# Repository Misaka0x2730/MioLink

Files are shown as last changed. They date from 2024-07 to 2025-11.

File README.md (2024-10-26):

# MioLink

This project is a port of the [Black Magic Probe project](https://github.com/blackmagic-debug/blackmagic) to Raspberry Pi RP2040 (2 Cortex-M0+ cores at 125MHz) MCU.  
The project is a USB debugger that operates via JTAG and SWD interfaces, supporting many ARM Cortex processors ([see supported device list here](https://black-magic.org/supported-targets.html)).  
It also supports debug output via Serial Wire Output (SWO) and RTT. Additionally, the device has an extra UART serial port that can be accessed through a second Virtual COM port.  
This README contains only the basic information: information about the hardware, how to build the firmware and flash the probe.  
Detailed instructions on how to use the debugger, how to configure SWO, RTT and etc. will be posted later in [the project's wiki](https://github.com/Misaka0x2730/MioLink/wiki).

# Hardware
## General information
The main board for this device is *MioLink* ([rev. A](https://github.com/Misaka0x2730/MioLink/blob/main/hardware/revA/MioLink_revA.pdf)/[rev. B](https://github.com/Misaka0x2730/MioLink/blob/main/hardware/revB/MioLink_revB.pdf)): RP2040 + 16Mbit (2MiB) QSPI Flash memory (W25Q16).  
At this moment, there are two revisions of *MioLink*: rev. A and rev. B.  
You can find information about their differences [here](https://github.com/Misaka0x2730/MioLink/wiki/MioLink-revisions-comparsion).  
[MioLink_Pico](https://github.com/Misaka0x2730/MioLink/blob/main/hardware/MioLink_Pico/revA/MioLink_Pico_revA.pdf) is a breakout board for Pico and Pico W featuring a power switch and voltage converters.  
Standard Pico and Pico W boards are also supported.  
The device type is determined at runtime, so all boards use the same firmware.  
[MioLink_adapter](https://github.com/Misaka0x2730/MioLink/blob/main/hardware/MioLink_adapter/revA/MioLink_adapter_revA.pdf) is an adapter that allows you to connect the probe with target boards that have different types of connectors.  
You can find all hardware CAD files (designed in KiCad) [here](https://github.com/Misaka0x2730/MioLink/tree/main/hardware).  

## Pinout
### MioLink and MioLink_Pico target connector pinout
*MioLink* and *MioLink_Pico* use the standard ARM 10-pin 0.1" connector and has additional 4-pin 0.1" UART connector:  


Pin | Name  | Description              | Pin | Name          | Description
:--:|:-----:|:------------------------:|:---:|:-------------:|:-----------------------------------------------------------------------:
1   | VTref | Target reference voltage | 2   | SWDIO/TMS     | SWD Data input/output / JTAG Test mode select
3   | GND   | Ground                   | 4   | SWDCLK/TCK    | SWD Clock / JTAG Test clock
5   | GND   | Ground                   | 6   | SWO/TDO/RX    | SWO Trace output / JTAG Test data output / UART Probe RX (Target TX)
7   | NC    | Not connected            | 8   | NC/TDI/TX     | Not connected for SWD / JTAG Test data input / UART Probe TX (Target RX)
9   | GND   | Ground                   | 10  | RESET         | Reset pin

#### UART connector pinout:

Pin | Name | Description                    | Pin | Name  | Description
:--:|:----:|:------------------------------:|:---:|:-----:|:------------------------:
1   | RX   | UART Probe RX (UART Target TX) | 2   | VTref | Target reference voltage
3   | TX   | UART Probe TX (UART Target RX) | 4   | GND   | Ground

### Pico/Pico W pinout


Pin       | Name       | Description
:--------:|:----------:|:------------------------------------------------------------------------:
10 (GP7)  | RESET      | Reset pin
11 (GP8)  | TX         | UART Probe TX (UART Target RX)
12 (GP9)  | RX         | UART Probe RX (UART Target TX)
13        | GND        | Ground
14 (GP10) | SWDCLK/TCK | SWD Clock / JTAG Test clock
15 (GP11) | SWDIO/TMS  | SWD Data input/output / JTAG Test mode select
16 (GP12) | NC/TDI/TX  | Not connected for SWD / JTAG Test data input / UART Probe TX (Target RX)
17 (GP13) | SWO/TDO/RX | SWO Trace output / JTAG Test data output / UART Probe RX (Target TX)
36        | 3V3        | 3.3V output from Pico

## Connecting target to probe
### Information about the Vtref pin (pin 1)
PLEASE, note that the Vtref pin (pin 1) on *MioLink* and *MioLink_Pico* MUST always be connected (internally or externally) to the logic level voltage of the target being debugged (from 1.65V to 5.5V) to power the level shifters inside the probe.  
If the target device operates at a 3.3V logic level, this pin can be powered internally by the probe, also in this case, the target can be powered by the probe if needed, and the maximum current is specified in the table below, but be careful, accidentally connecting anything to this pin that is not rated for 3.3V may lead to irreversible damage to the external device.  
3.3V power supply on this pin can be enabled with the GDB command ```monitor tpwr enable``` and disabled with the command ```monitor tpwr disable```. By default (after probe reset), it's disabled.  
Pico and Pico W are also able to provide 3.3V power for target, but it is recommended to keep the load on this pin less than 300mA, for more information see chapter 2.1, page 8 in [Pico datasheet](https://datasheets.raspberrypi.com/pico/pico-datasheet.pdf) and chapter 2.1, page 9 in [Pico W datasheet](https://datasheets.raspberrypi.com/picow/pico-w-datasheet.pdf).  
In all other cases, the Vtref pin (pin 1) functions as an input and must be connected to the logic level voltage of the target device.  
The allowable voltage range is from 1.65V to 5.5V.  

#### Maximum output current of the Vtref pin (pin 1):

Board | Max current
:----:|:----------:
MioLink | rev.A: ~200 mA;  rev.B: ~350 mA (min. 300, max. 400)
MioLink_Pico | ~200 mA (min. 175, max. 234)
Pico or Pico W | ~300 mA from 3V3 pin,  see recommendations in  Pico and Pico W datasheets.

### JTAG pins description

Pin | Description
:----:|:----------:
Vtref | Target reference voltage
GND   | Ground
TMS   | Test mode select
TCK   | Test clock
TDO   | Test data output
TDI   | Test data input
RESET | Optional reset pin

### SWD pins description

Pin    | Description
:-----:|:----------:
Vtref  | Target reference voltage
GND    | Ground
SWDIO  | Data input/output
SWDCLK | Clock signal
RESET  | Optional reset pin

# Building and flashing the probe
## Requirements
The following tools are required to build this project:
- git
- make
- Python
- cmake
- gcc
- arm-none-eabi-gcc

## Install all requirements on Windows
The simplest way to build the firmware under Windows environment is to use MinGW64.

Build steps:
1. Download and install [MSYS2](https://www.msys2.org/);
2. Run mingw64;
3. Upgrade packets, MinGW64 will be restarted:  ```pacman -Syu```
4. Install all requirements:  ```pacman -S git mingw-w64-x86_64-python mingw-w64-x86_64-make mingw-w64-x86_64-cmake mingw-w64-x86_64-arm-none-eabi-gcc mingw-w64-x86_64-gcc```
5. Clone this project with submodules:  ```git clone --recurse-submodules https://github.com/Misaka0x2730/MioLink.git```
6. Change current dir:  ```cd MioLink/firmware```

## Install all requirements on Ubuntu
1. Download and install all requirements:
```
cd /opt
sudo wget "https://developer.arm.com/-/media/Files/downloads/gnu/13.3.rel1/binrel/arm-gnu-toolchain-13.3.rel1-x86_64-arm-none-eabi.tar.xz"
sudo tar -xf arm-gnu-toolchain-13.3.rel1-x86_64-arm-none-eabi.tar.xz
sudo rm arm-gnu-toolchain-13.3.rel1-x86_64-arm-none-eabi.tar.xz
echo 'export PATH="$PATH":/opt/arm-gnu-toolchain-13.3.rel1-x86_64-arm-none-eabi/bin' >> ~/.bashrc
sudo apt-get install git python3 cmake
```
2. Clone this project with submodules into home directory:
```
cd ~
git clone --recurse-submodules https://github.com/Misaka0x2730/MioLink.git
```
3. Change current dir:  ```cd MioLink/firmware```

## Build debug image:
1. Create working directory:  ```mkdir debug```
2. Go to working directory:  ```cd debug```
3. Run cmake:  ```cmake -DCMAKE_BUILD_TYPE=Debug -G "MinGW Makefiles" ..```
4. Build image:  ```cmake --build .```
5. Use ```MioLink.uf2``` to flash device via factory USB-MSC bootloader.

## Build release image:
1. Create working directory:  ```mkdir release```
2. Go to working directory:  ```cd release```
3. Run cmake:  ```cmake -DCMAKE_BUILD_TYPE=Release -G "MinGW Makefiles" ..```
4. Build image:  ```cmake --build .```
5. Use ```MioLink.uf2``` to flash device via factory USB-MSC bootloader.

## How to flash the probe
1. Disconnect USB cable;
2. Press BOOT (BOOTSEL on Pico and Pico W) button;
3. Connect USB cable to PC;
4. Release BOOT (BOOTSEL on Pico and Pico W) button;
5. Drag-and-Drop ```MioLink.uf2``` file to mass storage device;
6. The device will be flashed and rebooted automatically, after which it is ready for use.

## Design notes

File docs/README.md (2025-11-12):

# MioLink

This project is a port of the [Black Magic Probe project](https://github.com/blackmagic-debug/blackmagic) to Raspberry Pi RP2040 (2 Cortex-M0+ cores at 125MHz) MCU.  
The project is a USB debugger that supports a lot of ARM Cortex target processors ([see supported device list here](https://black-magic.org/supported-targets.html)) via SWD and JTAG interfaces.  
It also supports debug output via Serial Wire Output (SWO) and RTT. Additionally, the device has an extra UART serial port that can be accessed through a second Virtual COM port.  
This README contains only the basic information: information about the hardware, how to build the firmware and flash the probe.  
Detailed instructions on how to use the debugger, how to configure SWO, RTT and etc. you can find on [the project's wiki](https://github.com/Misaka0x2730/MioLink/wiki).

# Table of Content
- [Hardware](#hardware)
  - [General information](#general-information)
  - [Pinout](#pinout)
    - [MioLink and MioLink_Pico pinout](#miolink-and-miolink_pico-pinout)
      - [Target connector pinout](#target-connector-pinout)
      - [UART connector pinout](#uart-connector-pinout)
    - [Pico/Pico W pinout](#picopico-w-pinout)
  - [Connecting target to probe](#connecting-target-to-probe)
    - [Information about the Vtref pin (pin 1)](#information-about-the-vtref-pin-pin-1)
      - [Maximum output current of the Vtref pin (pin 1)](#maximum-output-current-of-the-vtref-pin-pin-1)
    - [JTAG pins description](#jtag-pins-description)
    - [SWD pins description](#swd-pins-description)
- [Building and flashing the probe](#building-and-flashing-the-probe)
  - [Requirements](#requirements)
  - [Build on Windows](#build-on-windows)
    - [Install all requirements and clone the repository](#install-all-requirements-and-clone-the-repository)
    - [Build debug image](#build-debug-image)
    - [Build release image](#build-release-image)
  - [Build on Ubuntu](#build-on-ubuntu)
    - [Install all requirements and clone the repository](#install-all-requirements-and-clone-the-repository-1)
    - [Build debug image](#build-debug-image-1)
    - [Build release image](#build-release-image-1)
  - [Build on Mac OS](#build-on-mac-os)
    - [Install all requirements and clone the repository](#install-all-requirements-and-clone-the-repository-2)
    - [Build debug image](#build-debug-image-2)
    - [Build release image](#build-release-image-2)
  - [How to flash the probe](#how-to-flash-the-probe)
- [Known issues](#known-issues)

# Hardware
## General information
The main board for this device is *MioLink* ([rev. A](https://github.com/Misaka0x2730/MioLink/blob/main/hardware/revA/MioLink_revA.pdf)/[rev. B](https://github.com/Misaka0x2730/MioLink/blob/main/hardware/revB/MioLink_revB.pdf)): RP2040 + 16Mbit (2MiB) QSPI Flash memory (W25Q16).  
At this moment, there are two revisions of *MioLink*: rev. A and rev. B.  
You can find information about their differences [here](https://github.com/Misaka0x2730/MioLink/wiki/MioLink-revisions-comparsion).  
[MioLink_Pico](https://github.com/Misaka0x2730/MioLink/blob/main/hardware/MioLink_Pico/revA/MioLink_Pico_revA.pdf) is a breakout board for Pico and Pico W featuring a power switch and voltage converters.  
Standard Pico and Pico W boards are also supported.  
The device type is determined at runtime, so all boards use the same firmware.  
[MioLink_adapter](https://github.com/Misaka0x2730/MioLink/blob/main/hardware/MioLink_adapter/revA/MioLink_adapter_revA.pdf) is an adapter that allows you to connect the probe with target boards that have different types of connectors.  
You can find all hardware CAD files (designed in KiCad) [here](https://github.com/Misaka0x2730/MioLink/tree/main/hardware).  

## Pinout
### MioLink and MioLink_Pico pinout
#### Target connector pinout
*MioLink* and *MioLink_Pico* use the standard ARM 10-pin 0.1" connector and has additional 4-pin 0.1" UART connector:  


Pin | Name  | Description              | Pin | Name          | Description
:--:|:-----:|:------------------------:|:---:|:-------------:|:-----------------------------------------------------------------------:
1   | VTref | Target reference voltage | 2   | SWDIO/TMS     | SWD Data input/output / JTAG Test mode select
3   | GND   | Ground                   | 4   | SWDCLK/TCK    | SWD Clock / JTAG Test clock
5   | GND   | Ground                   | 6   | SWO/TDO/RX    | SWO Trace output / JTAG Test data output / UART Probe RX (Target TX)
7   | NC    | Not connected            | 8   | NC/TDI/TX     | Not connected for SWD / JTAG Test data input / UART Probe TX (Target RX)
9   | GND   | Ground                   | 10  | RESET         | Reset pin

#### UART connector pinout:

Pin | Name | Description                    | Pin | Name  | Description
:--:|:----:|:------------------------------:|:---:|:-----:|:------------------------:
1   | RX   | UART Probe RX (UART Target TX) | 2   | VTref | Target reference voltage
3   | TX   | UART Probe TX (UART Target RX) | 4   | GND   | Ground

### Pico/Pico W pinout


Pin       | Name       | Description
:--------:|:----------:|:------------------------------------------------------------------------:
10 (GP7)  | RESET      | Reset pin
11 (GP8)  | TX         | UART Probe TX (UART Target RX)
12 (GP9)  | RX         | UART Probe RX (UART Target TX)
13        | GND        | Ground
14 (GP10) | SWDCLK/TCK | SWD Clock / JTAG Test clock
15 (GP11) | SWDIO/TMS  | SWD Data input/output / JTAG Test mode select
16 (GP12) | NC/TDI/TX  | Not connected for SWD / JTAG Test data input / UART Probe TX (Target RX)
17 (GP13) | SWO/TDO/RX | SWO Trace output / JTAG Test data output / UART Probe RX (Target TX)
36        | 3V3        | 3.3V output from Pico

## Connecting target to probe
### Information about the Vtref pin (pin 1)
PLEASE, note that the Vtref pin (pin 1) on *MioLink* and *MioLink_Pico* MUST always be connected (internally or externally) to the logic level voltage of the target being debugged (from 1.65V to 5.5V) to power the level shifters inside the probe.  
If the target device operates at a 3.3V logic level, this pin can be powered internally by the probe, also in this case, the target can be powered by the probe if needed, and the maximum current is specified in the table below, but be careful, accidentally connecting anything to this pin that is not rated for 3.3V may lead to irreversible damage to the external device.  
3.3V power supply on this pin can be enabled with the GDB command ```monitor tpwr enable``` and disabled with the command ```monitor tpwr disable```. By default (after probe reset), it's disabled.  
Pico and Pico W are also able to provide 3.3V power for target through 3V3(OUT) pin (pin 36), but it is recommended to keep the load on this pin less than 300mA, for more information see chapter 2.1, page 8 in [Pico datasheet](https://datasheets.raspberrypi.com/pico/pico-datasheet.pdf) and chapter 2.1, page 9 in [Pico W datasheet](https://datasheets.raspberrypi.com/picow/pico-w-datasheet.pdf).  
In all other cases, the Vtref pin (pin 1) functions as an input and must be connected to the logic level voltage of the target device.  
The allowable voltage range is from 1.65V to 5.5V.  

#### Maximum output current of the Vtref pin (pin 1):

Board | Max current
:----:|:----------:
MioLink | rev.A: ~200 mA;  rev.B: ~350 mA (min. 300, max. 400)
MioLink_Pico | ~200 mA (min. 175, max. 234)
Pico or Pico W | ~300 mA from 3V3 pin,  see recommendations in  Pico and Pico W datasheets.

### JTAG pins description

Pin | Description
:----:|:----------:
Vtref | Target reference voltage
GND   | Ground
TMS   | Test mode select
TCK   | Test clock
TDO   | Test data output
TDI   | Test data input
RESET | Optional reset pin

### SWD pins description

Pin    | Description
:-----:|:----------:
Vtref  | Target reference voltage
GND    | Ground
SWDIO  | Data input/output
SWDCLK | Clock signal
RESET  | Optional reset pin

# Building and flashing the probe
## Requirements
The following tools are required to build this project:
- git
- make
- Python
- cmake
- gcc
- arm-none-eabi-gcc

## Build on Windows
The simplest way to build the firmware under Windows environment is to use MinGW64.

### Install all requirements and clone the repository
1. Download and install [MSYS2](https://www.msys2.org/);
2. Run mingw64;
3. Upgrade packets, MinGW64 will be restarted:  ```pacman -Syu```
4. Install all requirements:  ```pacman -S git mingw-w64-x86_64-python mingw-w64-x86_64-make mingw-w64-x86_64-cmake mingw-w64-x86_64-arm-none-eabi-gcc mingw-w64-x86_64-gcc```
5. Clone this project with submodules:  ```git clone --recurse-submodules https://github.com/Misaka0x2730/MioLink.git```
6. Change current dir:  ```cd MioLink/firmware```

### Build debug image:
1. Create working directory:  ```mkdir debug```
2. Go to working directory:  ```cd debug```
3. Run cmake:  ```cmake -DCMAKE_BUILD_TYPE=Debug -G "MinGW Makefiles" ..```
4. Build image:  ```cmake --build .```
5. Use ```MioLink.uf2``` to flash device via factory USB-MSC bootloader.

### Build release image:
1. Create working directory:  ```mkdir release```
2. Go to working directory:  ```cd release```
3. Run cmake:  ```cmake -DCMAKE_BUILD_TYPE=Release -G "MinGW Makefiles" ..```
4. Build image:  ```cmake --build .```
5. Use ```MioLink.uf2``` to flash device via factory USB-MSC bootloader.

## Build on Ubuntu
### Install all requirements and clone the repository
1. Download and install all requirements:
```
cd /opt
sudo wget "https://developer.arm.com/-/media/Files/downloads/gnu/12.2.rel1/binrel/arm-gnu-toolchain-12.2.rel1-x86_64-arm-none-eabi.tar.xz"
sudo tar -xf arm-gnu-toolchain-12.2.rel1-x86_64-arm-none-eabi.tar.xz
sudo rm arm-gnu-toolchain-12.2.rel1-x86_64-arm-none-eabi.tar.xz
export PATH="$PATH":/opt/arm-gnu-toolchain-12.2.rel1-x86_64-arm-none-eabi/bin
sudo apt-get install git python3 cmake
```
Note: ```export PATH``` will set the path environment variable only for the current session.  
If you want to set PATH permanently, you need to add ```export PATH="$PATH":/opt/arm-gnu-toolchain-12.2.rel1-x86_64-arm-none-eabi/bin``` to your ```~/.profile``` or ```~/.bashrc```.

2. Clone this project with submodules into home directory:
```
cd ~
git clone --recurse-submodules https://github.com/Misaka0x2730/MioLink.git
```
3. Change current dir:  ```cd MioLink/firmware```

### Build debug image:
1. Create working directory:  ```mkdir debug```
2. Go to working directory:  ```cd debug```
3. Run cmake:  ```cmake -DCMAKE_BUILD_TYPE=Debug -G "Unix Makefiles" ..```
4. Build image:  ```cmake --build .```
5. Use ```MioLink.uf2``` to flash device via factory USB-MSC bootloader.

### Build release image:
1. Create working directory:  ```mkdir release```
2. Go to working directory:  ```cd release```
3. Run cmake:  ```cmake -DCMAKE_BUILD_TYPE=Release -G "Unix Makefiles" ..```
4. Build image:  ```cmake --build .```
5. Use ```MioLink.uf2``` to flash device via factory USB-MSC bootloader.

## Build on Mac OS
### Install all requirements and clone the repository
1. Open the terminal and run `xcode-select --install` to install Xcode Command Line Tools (includes `gcc` and `make`);
2. Download and install [CMake](https://cmake.org/download/) for your system;
3. Download and install [Arm GNU Toolchain](https://developer.arm.com/downloads/-/arm-gnu-toolchain-downloads) for your system;
4. Download and install [Python 3](https://www.python.org/downloads/macos/);
5. Clone this project with submodules:
```
git clone --recurse-submodules https://github.com/Misaka0x2730/MioLink.git
```
6. Change current dir:  ```cd MioLink/firmware```

### Build debug image:
1. Create working directory:  ```mkdir debug```
2. Go to working directory:  ```cd debug```
3. Run cmake:  ```cmake -DCMAKE_BUILD_TYPE=Debug -G "Unix Makefiles" ..```
4. Build image:  ```cmake --build .```
5. Use ```MioLink.uf2``` to flash device via factory USB-MSC bootloader.

### Build release image:
1. Create working directory:  ```mkdir release```
2. Go to working directory:  ```cd release```
3. Run cmake:  ```cmake -DCMAKE_BUILD_TYPE=Release -G "Unix Makefiles" ..```
4. Build image:  ```cmake --build .```
5. Use ```MioLink.uf2``` to flash device via factory USB-MSC bootloader.

## How to flash the probe
1. Disconnect USB cable;
2. Press BOOT (BOOTSEL on Pico and Pico W) button;
3. Connect USB cable to PC;
4. Release BOOT (BOOTSEL on Pico and Pico W) button;
5. Drag-and-Drop ```MioLink.uf2``` file to mass storage device;
6. The device will be flashed and rebooted automatically, after which it is ready for use.

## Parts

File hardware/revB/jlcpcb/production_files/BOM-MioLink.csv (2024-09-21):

Comment | Designator | Footprint | LCSC
1k | R1,R14,R18,R28,R32,R6,R7,R8 | R_0402_1005Metric | C11702
120Ohm/100MHz | FB2,FB3 | L_0603_1608Metric | C14709
100n | C10,C14,C15,C17,C18,C19,C20,C21,C22,C23,C24,C26,C27,C28,C29,C30,C31,C32,C33,C8 | C_0402_1005Metric | C1525
TLV62568DBV | U1 | SOT-23-5 | C163219
6.8pF | C3 | C_0402_1005Metric | C189470
10u | C1,C2,C4 | C_0603_1608Metric | C19702
RP2040 | U6 | QFN-56-1EP_7x7mm_P0.4mm_EP3.2x3.2mm | C2040
12MHz | Y1 | Crystal_SMD_3225-4Pin_3.2x2.5mm | C20625731
74LVC2T45DC | U10,U7,U8,U9 | VSSOP-8_2.3x2mm_P0.5mm | C22356905
100 | R20,R21,R22,R23,R24,R25,R26 | R_0402_1005Metric | C25076
27 | R16,R17 | R_0402_1005Metric | C25100
100k | R10,R11,R12,R27,R29,R4,R9 | R_0402_1005Metric | C25741
10k | R13,R19,R30 | R_0402_1005Metric | C25744
75k 1% | R15 | R_0402_1005Metric | C25798
4.7k | R31,R33 | R_0402_1005Metric | C25900
5.1k | R2,R5 | R_0402_1005Metric | C25905
453k | R3 | R_0402_1005Metric | C27009
BOOT | SW1 | SW_SPST_B3S-1000 | C2733655
2.2uH | L1 | L_Taiyo-Yuden_NR-30xx | C2844756
Target UART connector | J3 | PinHeader_2x02_P2.54mm_Horizontal | C2894982
LMV321IDCKR | U5 | SOT-353_SC-70-5 | C3029047
1u | C12,C16,C25,C5,C6,C7,C9 | C_0402_1005Metric | C52923
USB | J1 | USB_C_Receptacle_HRO_TYPE-C-31-M-12 | C5337088
TPS2553DBVR | U4 | SOT-23-6 | C55266
Probe MCU SWD | J2 | PinHeader_2x05_P1.27mm_Vertical_SMD | C598540
Target connector | J4 | IDC-Header_2x05_P2.54mm_Horizontal | C7434504
USBLC6-2SC6 | U2 | SOT-23-6 | C7519
16p | C11,C13 | C_0402_1005Metric | C77590
BSS138 | Q1 | SOT-23 | C82045
W25Q16JVSS | U3 | SOIC-8_5.23x5.23mm_P1.27mm | C82317
33Ohm/100MHz | FB1 | L_0603_1608Metric | C88984
ERR | D2 | LED_1206_3216Metric | C965822
ACT | D3 | LED_1206_3216Metric | C965823
SER | D4 | LED_1206_3216Metric | C965824
PWR | D1 | LED_1206_3216Metric | C965826
GND | TP3 | TestPoint_Keystone_5000-5004_Miniature
TARGET_VREF_PWR_EN | TP9 | TestPoint_Pad_D1.0mm
SWCLK | TP12 | TestPoint_Pad_D1.0mm
TARGET_PWR_~{FAULT} | TP10 | TestPoint_Pad_D1.0mm
GND | TP2 | TestPoint_Pad_D1.0mm
GND | TP20 | TestPoint_Pad_D1.0mm
GND | TP15 | TestPoint_Pad_D1.0mm
5V | TP8 | TestPoint_Pad_D1.0mm
LED_SER | TP7 | TestPoint_Pad_D1.0mm
GND | TP1 | TestPoint_Pad_D1.0mm
3V3 | TP6 | TestPoint_Pad_D1.0mm
GND | TP18 | TestPoint_Pad_D1.0mm
BOOT | TP16 | TestPoint_Pad_D1.0mm
TARGET_RST | TP19 | TestPoint_Pad_D1.0mm
GND | TP14 | TestPoint_Pad_D1.0mm
LED_ERR | TP4 | TestPoint_Pad_D1.0mm
LED_ACT | TP5 | TestPoint_Pad_D1.0mm
RST | TP11 | TestPoint_Pad_D1.0mm
TARGET_VREF_MEASURE | TP17 | TestPoint_Pad_D1.0mm
SWDIO | TP13 | TestPoint_Pad_D1.0mm

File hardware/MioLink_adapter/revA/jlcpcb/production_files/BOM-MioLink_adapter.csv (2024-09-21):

Comment | Designator | Footprint | LCSC
TC2030-IDC-NL | J4 | PinHeader_2x03_P2.54mm_Vertical
10-pin Cortex Debug 0.05" | J2 | PinHeader_2x05_P1.27mm_Vertical_SMD
ST-Link v3 STDC14 | J7 | PinHeader_2x07_P1.27mm_Vertical_SMD
ST-Link clone | J3 | IDC-Header_2x05_P2.54mm_Vertical
10-pin Cortex Debug 0.1" | J1 | IDC-Header_2x05_P2.54mm_Vertical
Standard JTAG | J5 | IDC-Header_2x10_P2.54mm_Vertical
Serial Interconnection | J8 | PinHeader_2x08_P2.54mm_Vertical
20-pin Cortex Debug + ETM | J6 | PinHeader_2x10_P1.27mm_Vertical_SMD
Target Serial | J9 | PinHeader_1x04_P2.54mm_Horizontal

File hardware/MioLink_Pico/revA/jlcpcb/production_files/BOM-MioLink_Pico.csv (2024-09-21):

Comment | Designator | Footprint | LCSC
1k | R1,R17,R2,R21,R3,R4 | R_0402_1005Metric | C11702
120Ohm/100MHz | FB1 | L_0603_1608Metric | C14709
100n | C1,C10,C11,C12,C13,C14,C3,C7,C8,C9 | C_0402_1005Metric | C1525
74LVC2T45DC | U4,U5,U6,U7 | VSSOP-8_2.3x2mm_P0.5mm | C22356905
100 | R10,R11,R12,R13,R14,R15,R16 | R_0402_1005Metric | C25076
100k | R18,R5,R6,R7,R8 | R_0402_1005Metric | C25741
10k | R19 | R_0402_1005Metric | C25744
133k 1% | R9 | R_0402_1005Metric | C25753
4.7k | R20,R22 | R_0402_1005Metric | C25900
Target UART connector | J2 | PinHeader_2x02_P2.54mm_Horizontal | C2894982
LMV321IDCKR | U2 | SOT-353_SC-70-5 | C3029047
1u | C2,C4,C5,C6 | C_0402_1005Metric | C52923
TPS2553DBVR | U1 | SOT-23-6 | C55266
Probe MCU SWD | J1 | PinHeader_2x05_P1.27mm_Vertical_SMD | C598540
Target connector | J3 | IDC-Header_2x05_P2.54mm_Horizontal | C7434504
BSS138 | Q1 | SOT-23 | C82045
ERR | D2 | LED_1206_3216Metric | C965822
ACT | D3 | LED_1206_3216Metric | C965823
SER | D4 | LED_1206_3216Metric | C965824
PWR | D1 | LED_1206_3216Metric | C965826
Pico | U3 | RPi_Pico_SMD_TH
GND | TP10 | TestPoint_Keystone_5000-5004_Miniature
TARGET_VREF_PWR_EN | TP4 | TestPoint_Pad_D1.0mm
SWCLK | TP7 | TestPoint_Pad_D1.0mm
TARGET_PWR_~{FAULT} | TP5 | TestPoint_Pad_D1.0mm
GND | TP14 | TestPoint_Pad_D1.0mm
LED_SER | TP3 | TestPoint_Pad_D1.0mm
GND | TP12 | TestPoint_Pad_D1.0mm
TARGET_RST | TP13 | TestPoint_Pad_D1.0mm
GND | TP9 | TestPoint_Pad_D1.0mm
LED_ERR | TP1 | TestPoint_Pad_D1.0mm
LED_ACT | TP2 | TestPoint_Pad_D1.0mm
RST | TP6 | TestPoint_Pad_D1.0mm
TARGET_VREF_MEASURE | TP11 | TestPoint_Pad_D1.0mm
SWDIO | TP8 | TestPoint_Pad_D1.0mm

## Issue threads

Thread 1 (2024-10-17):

Question regarding use of U9 in revB schematic

L0rdL4nx, 2024-10-17:
Hi,

I really like your  project and am rebuilding it myself at the moment.
Since I will be using other level shifters (I got some unidirectional high speed ones lying around + some BBS138's), I was wondering about your level-shifter designs. For TMS/SWDIO you are using another 74LVCT45DC (U9). Is there any specific reason for that (switching speed?), would just a BBS138 not be sufficient?
I'm not quite stocked about having to order for just that part, because I basically have everything else at hand...

A quick reply would be appreciated :)

Misaka0x2730, 2024-10-17:
Hi!
Yeah, the switching speed is the main reason.
For example, if you use only BS138 in the classic level shifter schematic on N-MOSFET (on the screenshot), then there is no problem with logic 0, but logic 1 is set on the line by only pull-ups, so there may be problems with rising edge (from 0 to 1) at high frequencies.
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

L0rdL4nx, 2024-10-17:
Thanks for your (I have to admit, **very** quick) reply :)

That circuit was exactly what I was thinking about. But sure, if the switching frequency doesn't allow for it I probably have to get some of those translator chips. Just out of curiosity, what exactly does the SWDIO use for a switching frequency/data rate (JTAG TMS frequency is low enough as far as I know)?
BSS138 datasheet says something around 20-40ns switching time, the actual rise time in circuit is propably quite a bit higher...

Also, I will still propably adapt the circuit to accomnodate the [TXU0204](https://www.ti.com/lit/ds/symlink/txu0204-q1.pdf?ts=1729106228717), just because I have enough of them and don't need them any time soon.

Misaka0x2730, 2024-10-17:
You're right, the JTAG TMS frequency is not very high, but the TCK frequency is high and since the JTAG interface is synchronous, then the correct level must be set on the TMS line at the front on the TCK line. In other words, it's not the frequency that matters, but the slew rate.
And the second, most important point is that the TMS line is the SWDIO line in the SWD mode and in this case the frequency there is very high. And that's why we need to control the TMS pin direction.

L0rdL4nx, 2024-10-18:
Oh yea, I can see what you mean. Even without the capacitance of the traces and the resistors it looks horrible...
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

Still looking for a spice model of the TXU0204, I just want to see how it would react if I "daisy-chain" two channels with high frequency diodes ([BAS32L](https://assets.nexperia.com/documents/data-sheet/BAS32L.pdf)), to make bi-unidirectional channel.

Nvtl I will propably just get a 74LVCT45DC's for SWDIO; my main focus is to debug other RP2040s so I need the SWD interface.

Misaka0x2730, 2024-10-18:
Exactly, I simulated it with 2N7002 and even without significant load on 1MHz it will never reach 5V on the high side
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

With small capacitance it will look even worse:
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

Misaka0x2730, 2024-10-18:
There is one way you can improve the edge response - reduce R1 and R2 value, with 1kOhm it will work on 1MHz
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

L0rdL4nx, 2024-10-21:
Oh sorry, I completly forgot to close it as completed.

I didn't have that much time on the weekend, but I'm planning on doing some more work on my own PCB in the next days. In theory and according to the datasheet I _should_ be able to do something like that:
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

Never the less I will propably still go the "save" route and use your (BMP is using the exact same I believe) proven as working design; just to be sure that's not the point of failure xD

Thanks a lot for your help here and especially for releasing your work as open-source.

Closed 2024-10-21.

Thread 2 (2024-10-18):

Verification failed on STM32F103 target on interface frequency >1MHz in the debug configuration

Misaka0x2730, 2024-10-18:
When target is STM32F103, if MioLink is flashed with a debug firmware, at interface frequency higher than 1MHz, firmware verification (compare-sections) almost always fails (one or more sections - MIS-MATCHED).
This occurs when working over both SWD and JTAG.
In the release configuration, everything works fine, even at a frequency of 10MHz.

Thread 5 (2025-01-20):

Prebuilt purchase?

wafflexyzz, 2025-01-20:
Can you order the miolink or railink already built from tindie or anywhere else as a way to support you and get a ready made pcb?

Misaka0x2730, 2025-01-21:
@wafflexyzz Wow, thank you so much for paying attention to my project - I really appreciate it.
I apologize for the late reply, but I’m in Russia, and I’m afraid that under current circumstances, releasing pre-assembled devices on Tindie isn’t possible.
If you live in a country that still has regular postal service from Russia, please let me know, and I’ll send you 1-2 units of rev. B completely free (you only have to cover shipping costs).
Your interest in my project is a form of support that means far more to me than any amount of money.

wafflexyzz, 2025-01-22:
Wow thank you and thats unfortunate that you cant sell both the miolink and the railink i think they are both really great designs and make something like a jlink accessible to people who dont have $1000 to spend on a jlink. Anyway, im in Australia, is that somewhere that russia can post too? Again thanks sk much for your generosity!

Misaka0x2730, 2025-01-24:
Unfortunately, the options for sending anything from Russia to Australia are currently extremely limited.
Otherwise, it would cost a completely unreasonable amount of money.

If you need a debugger for non-commercial use, from what you can find and purchase, I can recommend the J-Link Edu Mini, which costs about 60 US$.

wafflexyzz, 2025-01-30:
Damn that totally sucks. What countries are all good to send to i might be able to organise mail forwarding from an affordable country for postage from russia. Im not super up to date with world politics but I hope you are still able to to live your life the way you want to live it. Its certainly something that we take for granted in Australia!On 25 Jan 2025, at 12:12 am, Dmitry Rezvanov ***@***.***> wrote:
Unfortunately, the options for sending anything from Russia to Australia are currently extremely limited.
Otherwise, it would cost a completely unreasonable amount of money.
If you need a debugger for non-commercial use, from what you can find and purchase, I can recommend the J-Link Edu Mini, which costs about 60 US$.

—Reply to this email directly, view it on GitHub, or unsubscribe.You are receiving this because you were mentioned.Message ID: ***@***.***>

Closed 2025-02-14.

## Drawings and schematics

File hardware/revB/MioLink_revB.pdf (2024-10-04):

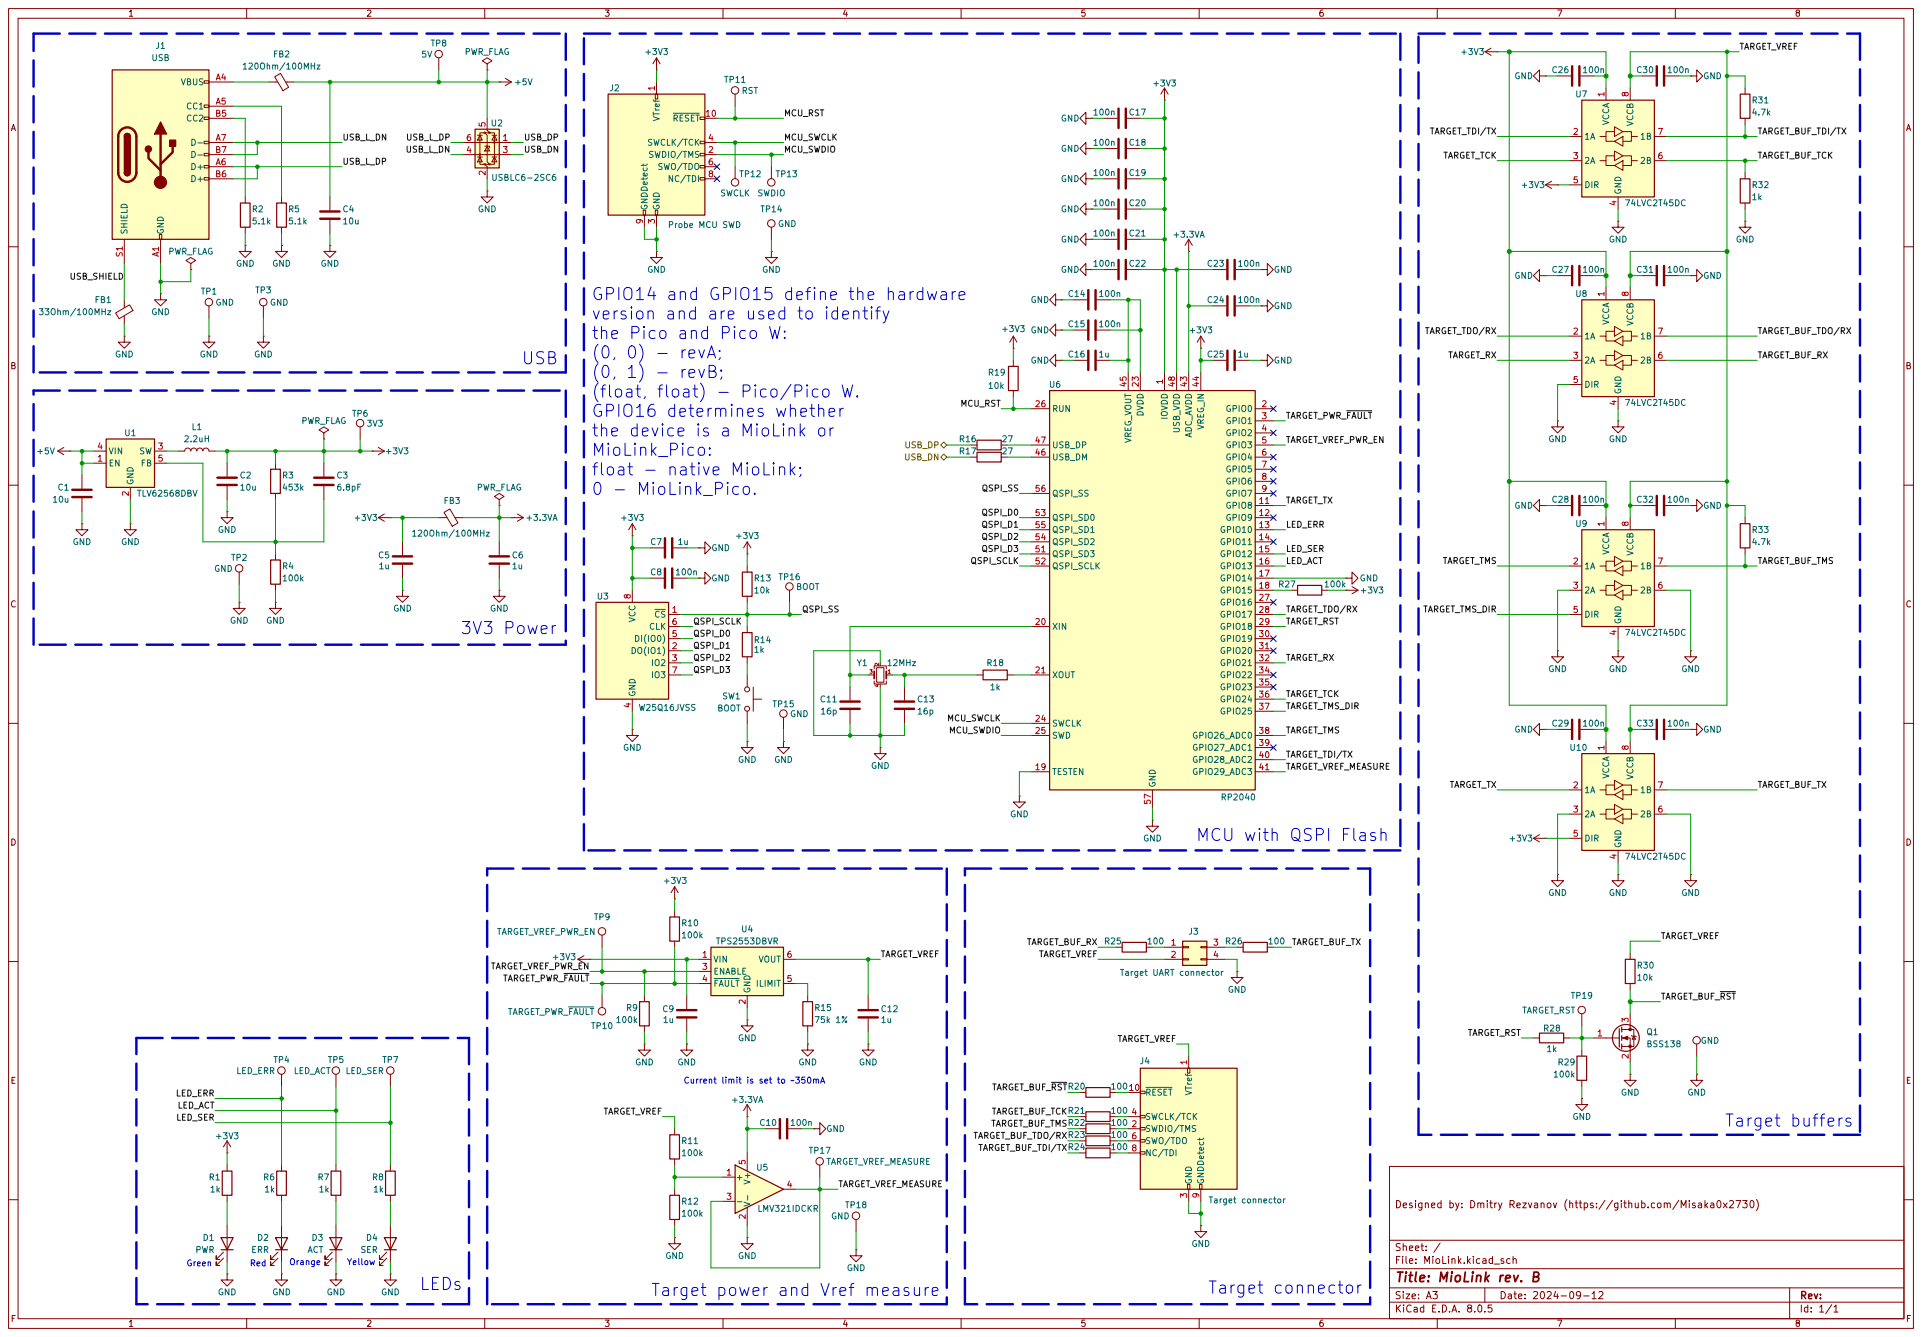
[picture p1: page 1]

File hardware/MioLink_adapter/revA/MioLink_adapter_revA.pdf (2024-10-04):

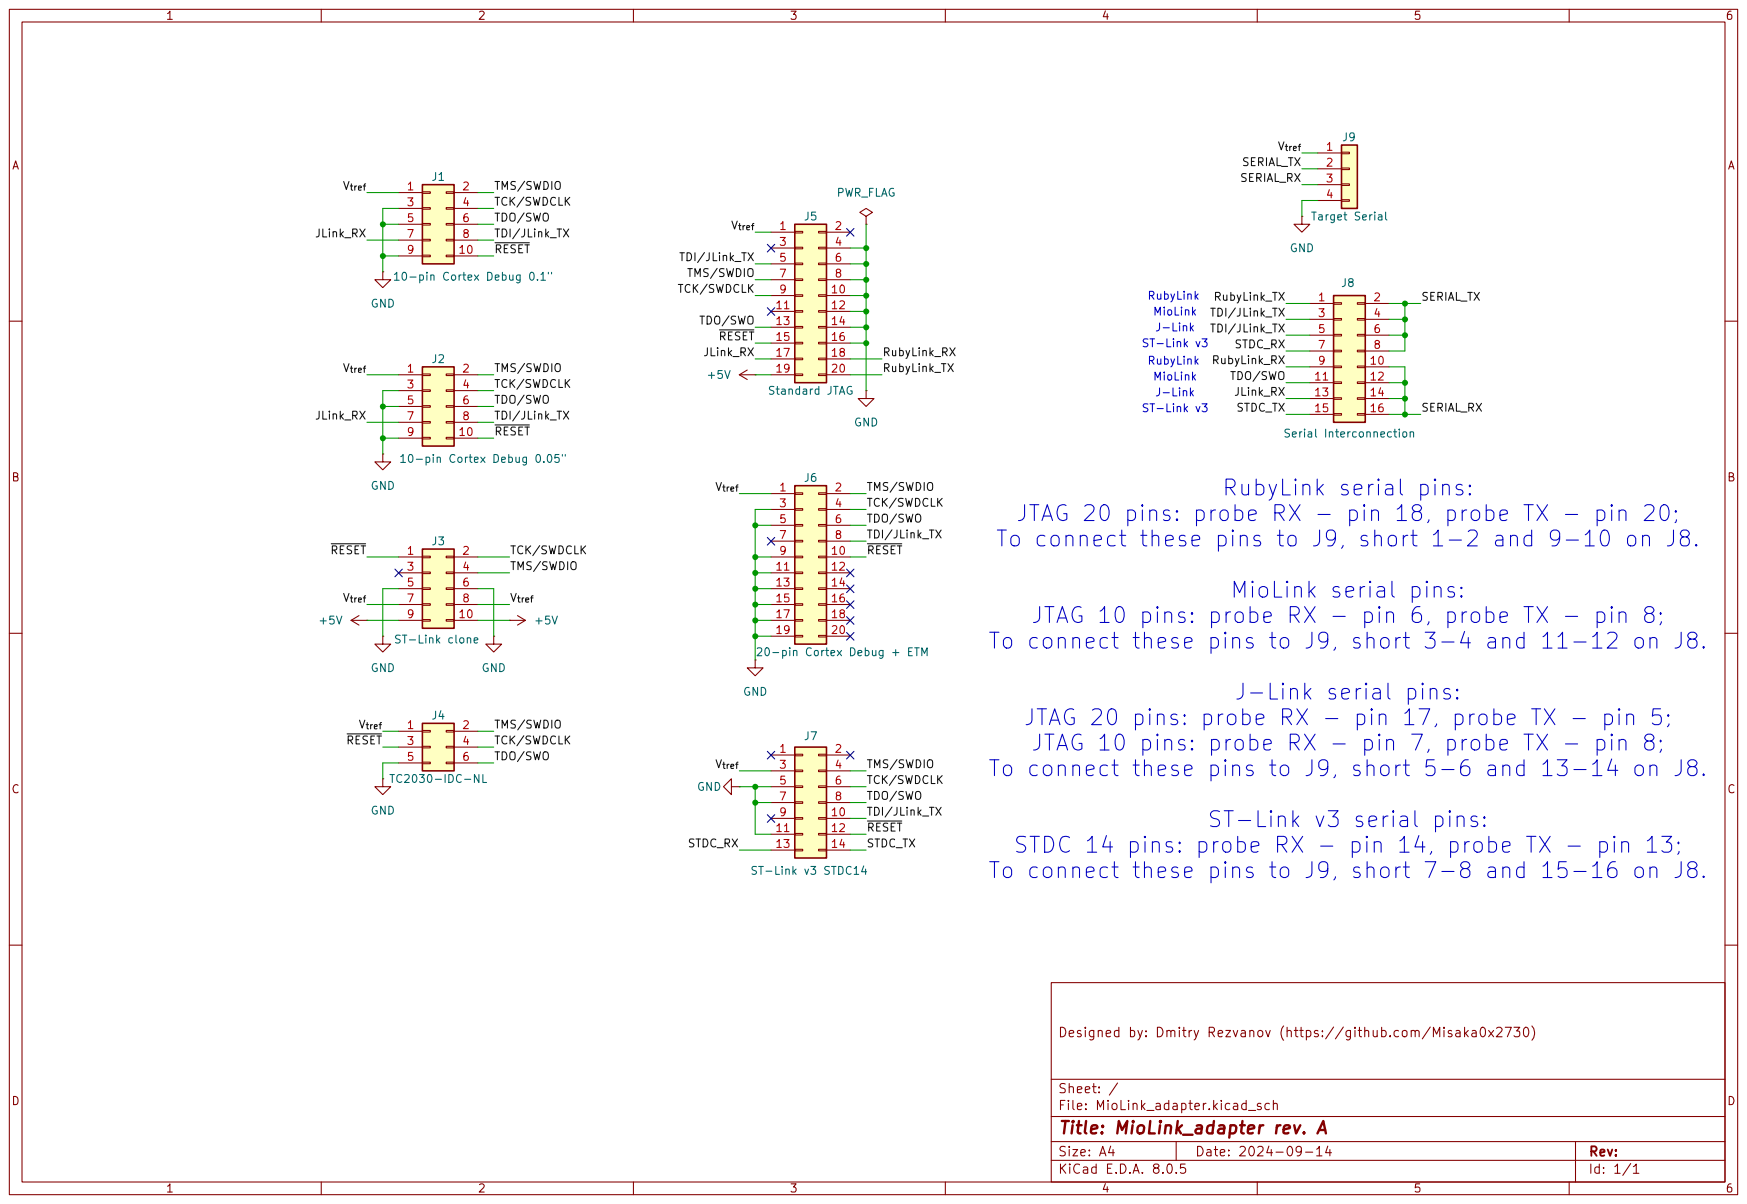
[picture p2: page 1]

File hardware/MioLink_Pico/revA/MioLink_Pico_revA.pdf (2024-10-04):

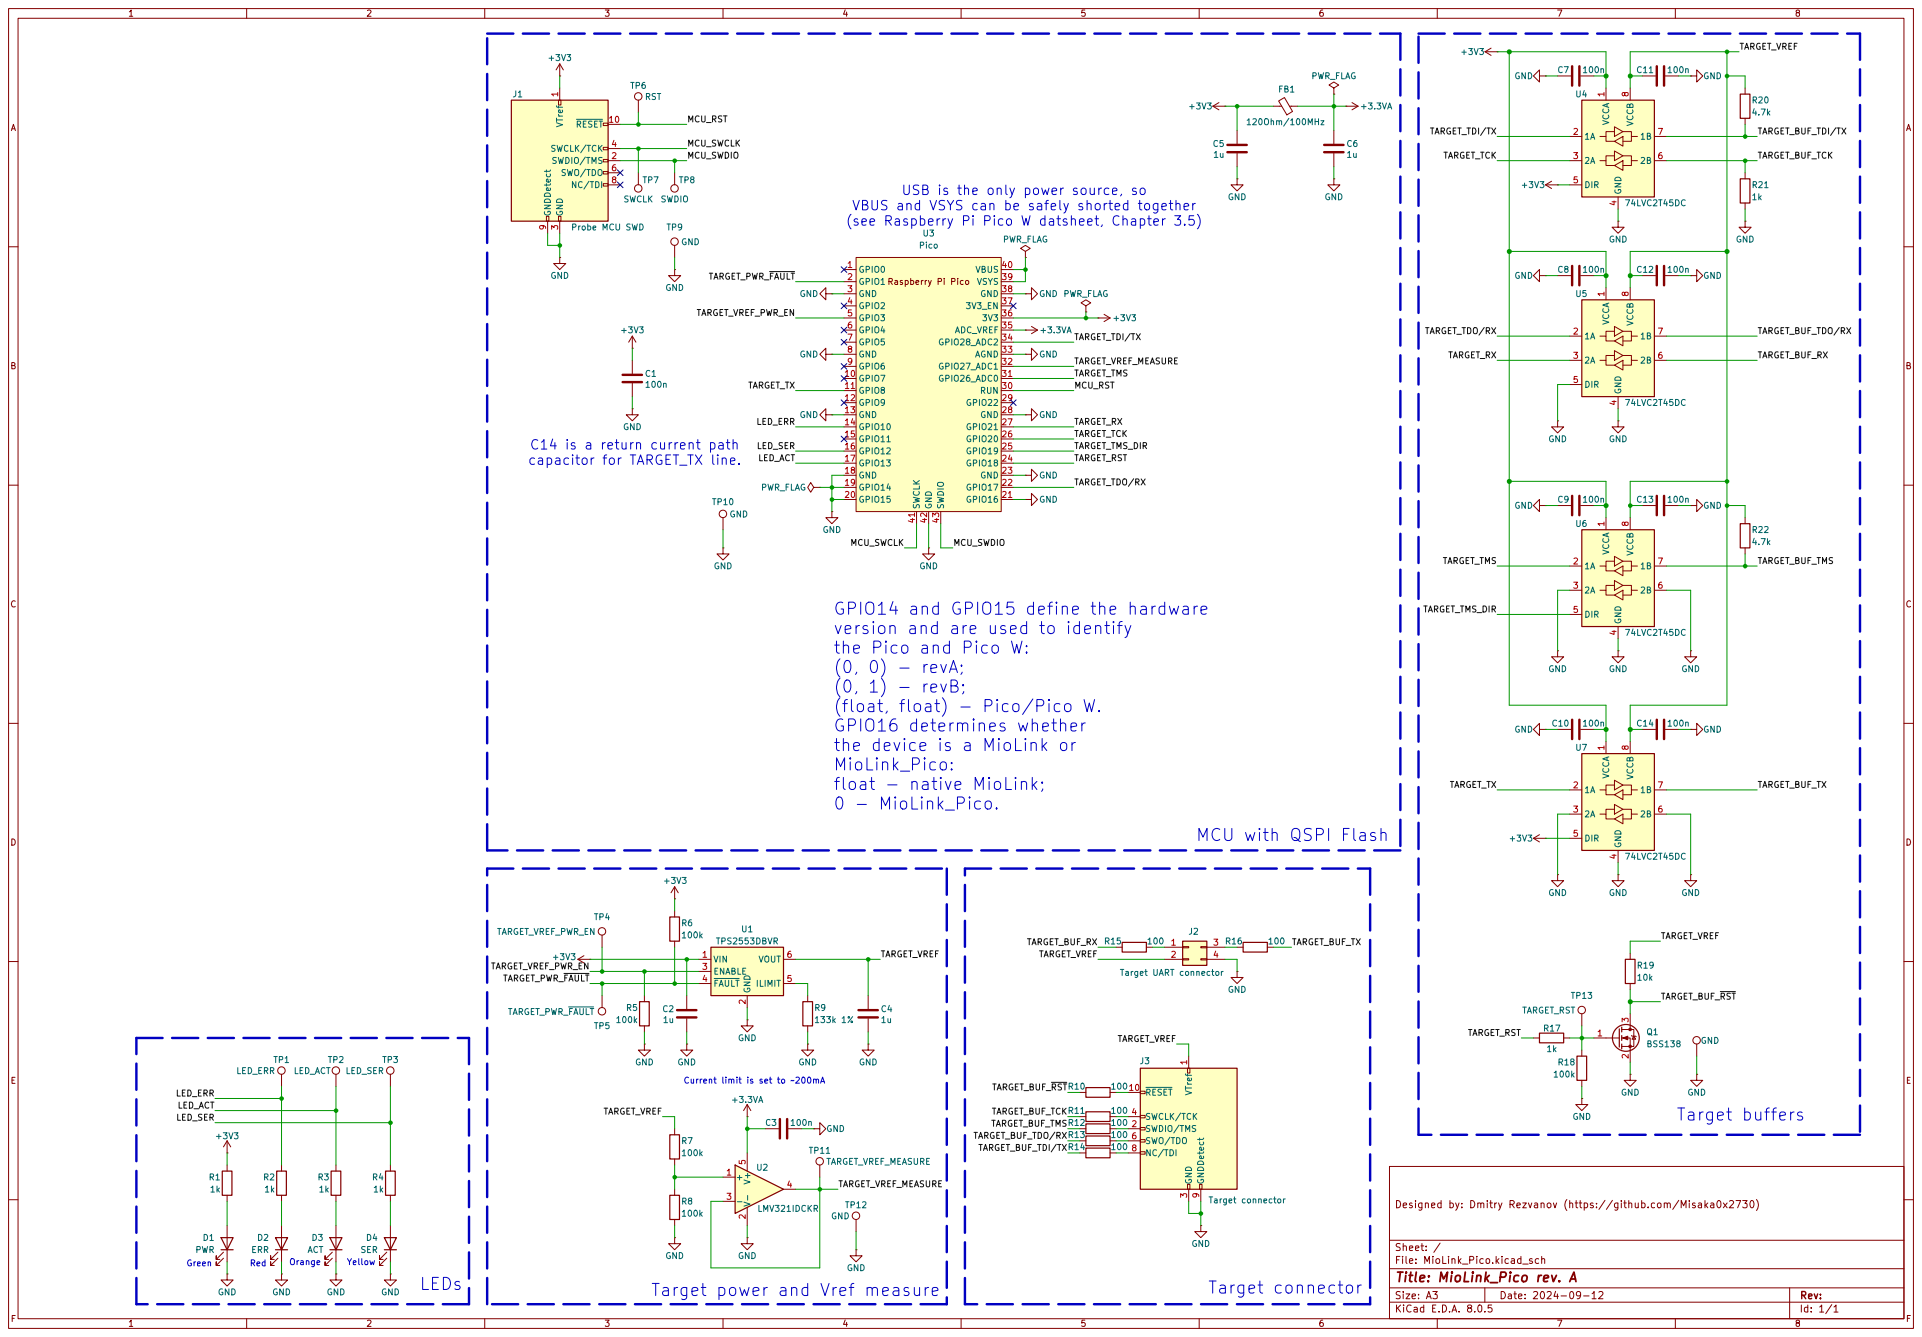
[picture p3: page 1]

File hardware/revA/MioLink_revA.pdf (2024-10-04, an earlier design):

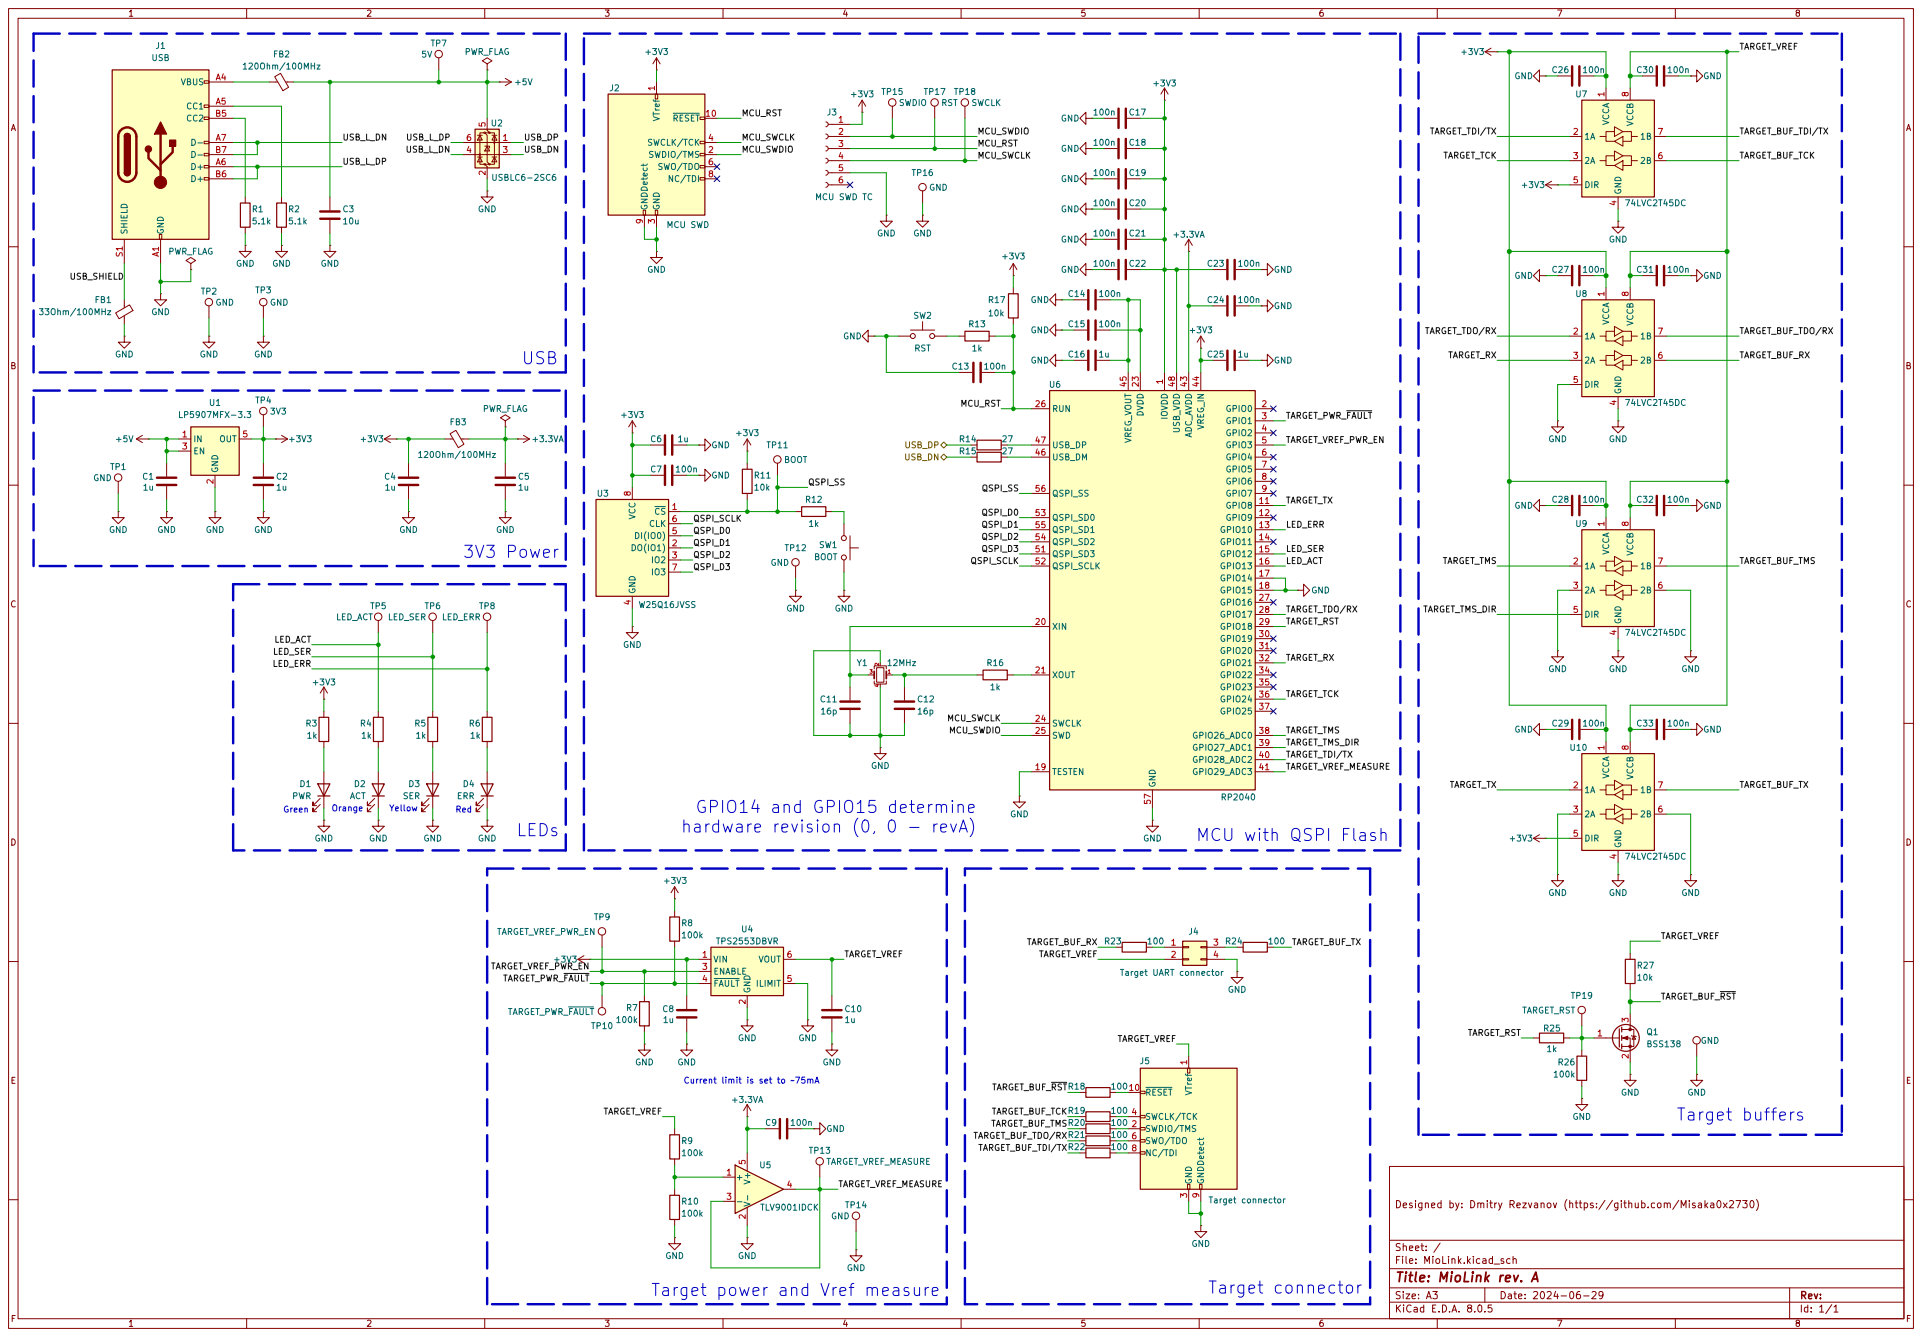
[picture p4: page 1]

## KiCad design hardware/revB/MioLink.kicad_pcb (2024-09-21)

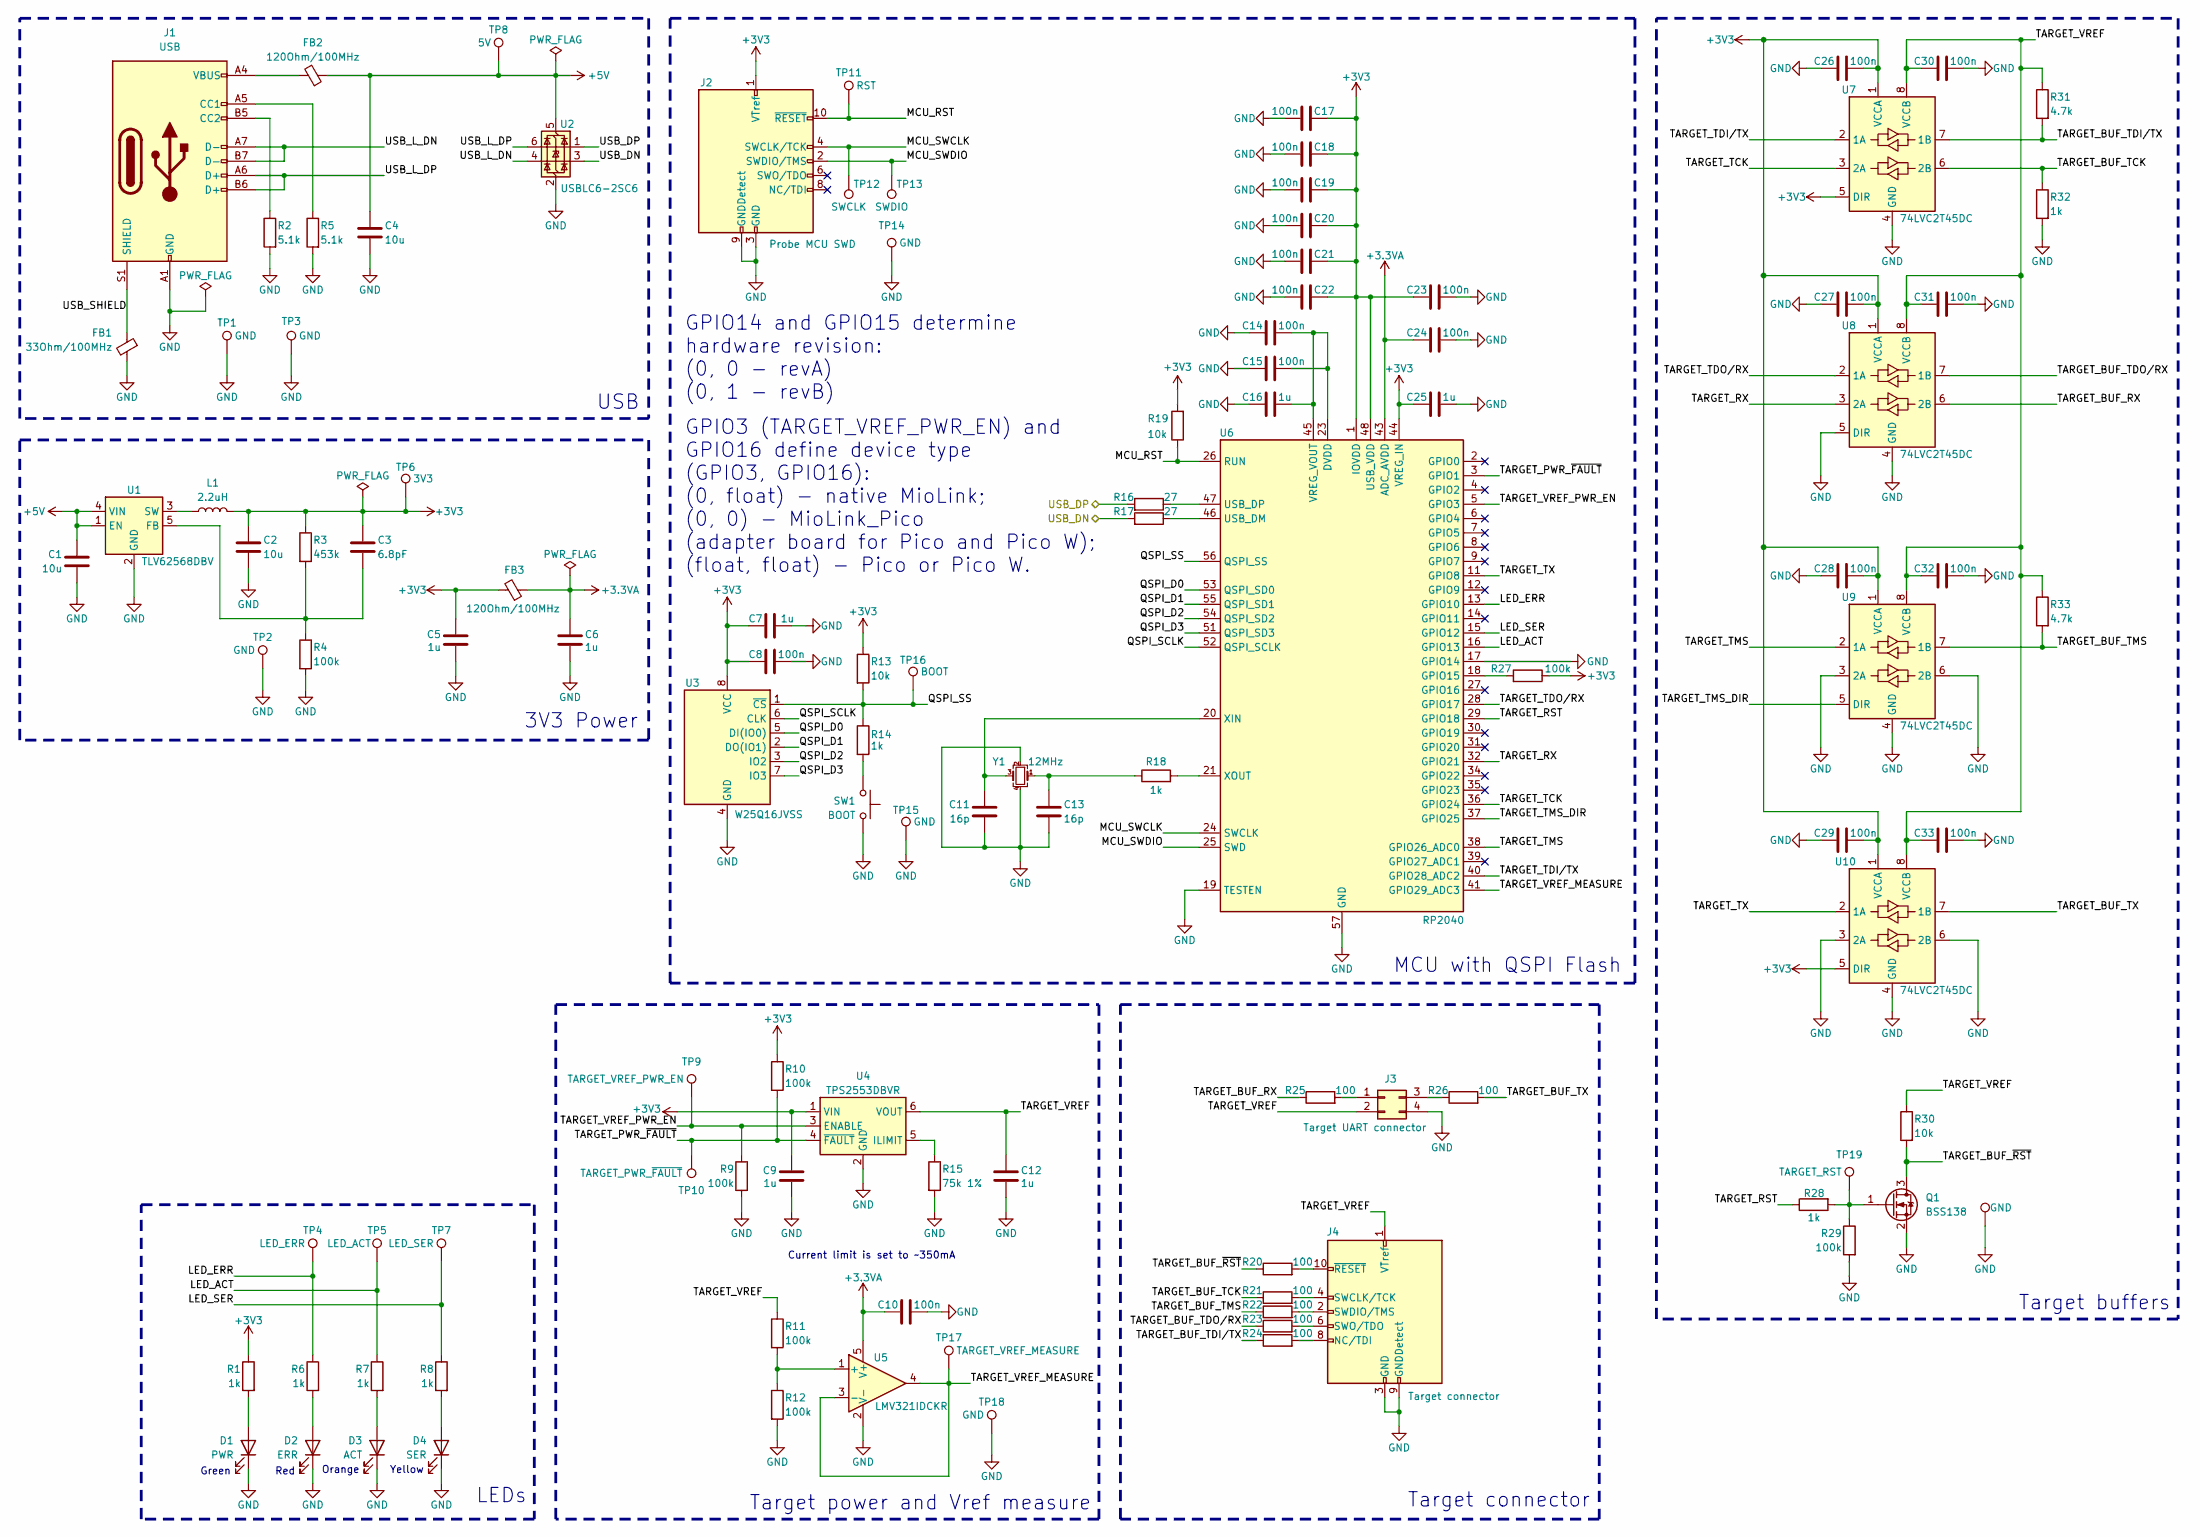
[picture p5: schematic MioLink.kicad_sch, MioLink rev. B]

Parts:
C1, C2, C4: 10u; C_0603_1608Metric; Part Number CL10A106KP8NNNC; LCSC C19702
C3: 6.8pF; C_0402_1005Metric; Part Number CC0402CRNPO9BN6R8; LCSC C189470
C5, C6, C7, C9, C12, C16, C25: 1u; C_0402_1005Metric; Part Number CL05A105KA5NQNC; LCSC C52923
C8, C10, C14, C15, C17, C18, C19, C20, C21, C22, C23, C24, C26, C27, C28, C29, C30, C31, C32, C33: 100n; C_0402_1005Metric; Part Number CL05B104KO5NNNC; LCSC C1525
C11, C13: 16p; C_0402_1005Metric; Part Number CC0402JRNPO9BN160; LCSC C77590
D1: PWR; LED_1206_3216Metric; Part Number XL-3216SYGC; LCSC C965826
D2: ERR; LED_1206_3216Metric; Part Number XL-3216SURC; LCSC C965822
D3: ACT; LED_1206_3216Metric; Part Number XL-3216UOC; LCSC C965823
D4: SER; LED_1206_3216Metric; Part Number XL-3216UYC; LCSC C965824
FB1: 33Ohm/100MHz; L_0603_1608Metric; Part Number BLM18PG330SN1D; LCSC C88984
FB2, FB3: 120Ohm/100MHz; L_0603_1608Metric; Part Number BLM18PG121SN1D; LCSC C14709
J1: USB; USB_C_Receptacle_HRO_TYPE-C-31-M-12; Part Number TYPE-C-31-M-12A; LCSC C5337088
J2: Probe MCU SWD; PinHeader_2x05_P1.27mm_Vertical_SMD; Part Number 20021121-00010T4LF; LCSC C598540
J3: Target UART connector; PinHeader_2x02_P2.54mm_Horizontal; Part Number PZ254-2-02-W-8.5; LCSC C2894982
J4: Target connector; IDC-Header_2x05_P2.54mm_Horizontal; Part Number 0502A001A1BC; LCSC C7434504
L1: 2.2uH; L_Taiyo-Yuden_NR-30xx; Part Number LPS3015-222MRC; LCSC C2844756
Q1: BSS138; SOT-23; Part Number BSS138LT1G; LCSC C82045
R1, R6, R7, R8, R14, R18, R28, R32: 1k; R_0402_1005Metric; Part Number 0402WGF1001TCE; LCSC C11702
R2, R5: 5.1k; R_0402_1005Metric; Part Number 0402WGF5101TCE; LCSC C25905
R3: 453k; R_0402_1005Metric; Part Number AC0402FR-07453KL; LCSC C27009
R4, R9, R10, R11, R12, R27, R29: 100k; R_0402_1005Metric; Part Number 0402WGF1003TCE; LCSC C25741
R13, R19, R30: 10k; R_0402_1005Metric; Part Number 0402WGF1002TCE; LCSC C25744
R15: 75k 1%; R_0402_1005Metric; Part Number 0402WGF7502TCE; LCSC C25798
R16, R17: 27; R_0402_1005Metric; Part Number 0402WGF270JTCE; LCSC C25100
R20, R21, R22, R23, R24, R25, R26: 100; R_0402_1005Metric; Part Number 0402WGF1000TCE; LCSC C25076
R31, R33: 4.7k; R_0402_1005Metric; Part Number 0402WGF4701TCE; LCSC C25900
SW1: BOOT; SW_SPST_B3S-1000; Part Number B3S-1000; LCSC C2733655
TP1, TP2, TP14, TP15, TP18, TP20: GND; TestPoint_Pad_D1.0mm
TP3: GND; TestPoint_Keystone_5000-5004_Miniature
TP4: LED_ERR; TestPoint_Pad_D1.0mm
TP5: LED_ACT; TestPoint_Pad_D1.0mm
TP6: 3V3; TestPoint_Pad_D1.0mm
TP7: LED_SER; TestPoint_Pad_D1.0mm
TP8: 5V; TestPoint_Pad_D1.0mm
TP9: TARGET_VREF_PWR_EN; TestPoint_Pad_D1.0mm
TP10: TARGET_PWR_~{FAULT}; TestPoint_Pad_D1.0mm
TP11: RST; TestPoint_Pad_D1.0mm
TP12: SWCLK; TestPoint_Pad_D1.0mm
TP13: SWDIO; TestPoint_Pad_D1.0mm
TP16: BOOT; TestPoint_Pad_D1.0mm
TP17: TARGET_VREF_MEASURE; TestPoint_Pad_D1.0mm
TP19: TARGET_RST; TestPoint_Pad_D1.0mm
U1: TLV62568DBV; SOT-23-5; Part Number TLV62568DBV; LCSC C163219
U2: USBLC6-2SC6; SOT-23-6; Part Number USBLC6-2SC6; LCSC C7519
U3: W25Q16JVSS; SOIC-8_5.23x5.23mm_P1.27mm; Part Number W25Q16JVSSIQ; LCSC C82317
U4: TPS2553DBVR; SOT-23-6; Part Number TPS2553DBV; LCSC C55266
U5: LMV321IDCKR; SOT-353_SC-70-5; Part Number LMV321IDCKR; LCSC C3029047
U6: RP2040; QFN-56-1EP_7x7mm_P0.4mm_EP3.2x3.2mm; Part Number RP2040; LCSC C2040
U7, U8, U9, U10: 74LVC2T45DC; VSSOP-8_2.3x2mm_P0.5mm; Part Number SN74LVC2T45DCU; LCSC C22356905
Y1: 12MHz; Crystal_SMD_3225-4Pin_3.2x2.5mm; Part Number ABM8-272-T3; LCSC C20625731

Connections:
+3.3VA: C6.1, C10.1, C24.1, FB3.1, U5.5 (V+), U6.43 (ADC_AVDD)
+3V3: C2.1, C3.1, C5.1, C7.1, C8.1, C9.1, C17.1, C18.1, C19.1, C20.1, C21.1, C22.1, C23.1, C25.1, C26.1, C27.1, C28.1, C29.1, FB3.2, J2.1 (VTref), L1.2, R1.1, R3.1, R10.1, R13.1, R19.2, R27.1, TP6.1, U3.8 (VCC), U4.1 (VIN), U6.1 (IOVDD), U6.10 (IOVDD), U6.22 (IOVDD), U6.33 (IOVDD), U6.42 (IOVDD), U6.44 (VREG_IN), U6.48 (USB_VDD), U6.49 (IOVDD), U7.1 (VCCA), U7.5 (DIR), U8.1 (VCCA), U9.1 (VCCA), U10.1 (VCCA), U10.5 (DIR)
+5V: C1.2, C4.1, FB2.1, TP8.1, U1.1 (EN), U1.4 (VIN), U2.5 (VBUS)
/LED_ACT: R7.1, TP5.1, U6.16 (GPIO13)
/LED_ERR: R6.1, TP4.1, U6.13 (GPIO10)
/LED_SER: R8.1, TP7.1, U6.15 (GPIO12)
/MCU_RST: J2.10 (~RESET), R19.1, TP11.1, U6.26 (RUN)
/MCU_SWCLK: J2.4 (SWCLK/TCK), TP12.1, U6.24 (SWCLK)
/MCU_SWDIO: J2.2 (SWDIO/TMS), TP13.1, U6.25 (SWD)
/QSPI_D0: U3.5 (DI(IO0)), U6.53 (QSPI_SD0)
/QSPI_D1: U3.2 (DO(IO1)), U6.55 (QSPI_SD1)
/QSPI_D2: U3.3 (IO2), U6.54 (QSPI_SD2)
/QSPI_D3: U3.7 (IO3), U6.51 (QSPI_SD3)
/QSPI_SCLK: U3.6 (CLK), U6.52 (QSPI_SCLK)
/QSPI_SS: R13.2, R14.1, TP16.1, U3.1 (~CS), U6.56 (QSPI_SS)
/TARGET_BUF_RX: R25.1, U8.6 (2B)
/TARGET_BUF_TCK: R21.1, R32.1, U7.6 (2B)
/TARGET_BUF_TDI/TX: R24.1, R31.2, U7.7 (1B)
/TARGET_BUF_TDO/RX: R23.1, U8.7 (1B)
/TARGET_BUF_TMS: R22.1, R33.2, U9.7 (1B)
/TARGET_BUF_TX: R26.2, U10.7 (1B)
/TARGET_BUF_~RST: Q1.3 (D), R20.1, R30.2
/TARGET_PWR_~FAULT: R10.2, TP10.1, U4.4 (~FAULT), U6.3 (GPIO1)
/TARGET_RST: R28.1, U6.29 (GPIO18)
/TARGET_RX: U6.32 (GPIO21), U8.3 (2A)
/TARGET_TCK: U6.36 (GPIO24), U7.3 (2A)
/TARGET_TDI/TX: U6.40 (GPIO28_ADC2), U7.2 (1A)
/TARGET_TDO/RX: U6.28 (GPIO17), U8.2 (1A)
/TARGET_TMS: U6.38 (GPIO26_ADC0), U9.2 (1A)
/TARGET_TMS_DIR: U6.37 (GPIO25), U9.5 (DIR)
/TARGET_TX: U6.11 (GPIO8), U10.2 (1A)
/TARGET_VREF: C12.1, C30.2, C31.2, C32.2, C33.2, J3.2, J4.1 (VTref), R11.1, R30.1, R31.1, R33.1, U4.6 (VOUT), U7.8 (VCCB), U8.8 (VCCB), U9.8 (VCCB), U10.8 (VCCB)
/TARGET_VREF_MEASURE: TP17.1, U5.3 (-), U5.4, U6.41 (GPIO29_ADC3)
/TARGET_VREF_PWR_EN: R9.1, TP9.1, U4.3 (ENABLE), U6.5 (GPIO3)
/USB_DN: R17.2, U2.3 (I/O2)
/USB_DP: R16.2, U2.1 (I/O1)
/USB_L_DN: J1.A7 (D-), J1.B7 (D-), U2.4 (I/O2)
/USB_L_DP: J1.A6 (D+), J1.B6 (D+), U2.6 (I/O1)
/USB_SHIELD: FB1.1, J1.S1 (SHIELD)
GND: C1.1, C2.2, C4.2, C5.2, C6.2, C7.2, C8.2, C9.2, C10.2, C11.2, C12.2, C13.2, C14.1, C15.1, C16.1, C17.2, C18.2, C19.2, C20.2, C21.2, C22.2, C23.2, C24.2, C25.2, C26.2, C27.2, C28.2, C29.2, C30.1, C31.1, C32.1, C33.1, D1.1 (K), D2.1 (K), D3.1 (K), D4.1 (K), FB1.2, J1.A1 (GND), J1.A12 (GND), J1.B1 (GND), J1.B12 (GND), J2.3 (GND), J2.5 (GND), J2.9 (GNDDetect), J3.4, J4.3 (GND), J4.5 (GND), J4.9 (GNDDetect), Q1.2 (S), R2.2, R4.2, R5.2, R9.2, R12.2, R15.2, R29.2, R32.2, SW1.1, TP1.1, TP2.1, TP3.1, TP14.1, TP15.1, TP18.1, TP20.1, U1.2 (GND), U2.2 (GND), U3.4 (GND), U4.2 (GND), U5.2 (V-), U6.17 (GPIO14), U6.19 (TESTEN), U6.57 (GND), U7.4 (GND), U8.4 (GND), U8.5 (DIR), U9.3 (2A), U9.4 (GND), U9.6 (2B), U10.3 (2A), U10.4 (GND), U10.6 (2B), Y1.2, Y1.4
unnamed: C13.1, R18.1, Y1.1
unnamed: D1.2 (A), R1.2
unnamed: D2.2 (A), R6.2
unnamed: D3.2 (A), R7.2
unnamed: D4.2 (A), R8.2
unnamed: FB2.2, J1.A4 (VBUS), J1.A9 (VBUS), J1.B4 (VBUS), J1.B9 (VBUS)
unnamed: J1.A5 (CC1), R5.1
unnamed: J1.B5 (CC2), R2.1
unnamed: J3.1, R25.2
unnamed: J3.3, R26.1
unnamed: J4.8 (NC/TDI), R24.2
unnamed: J4.4 (SWCLK/TCK), R21.2
unnamed: J4.2 (SWDIO/TMS), R22.2
unnamed: J4.6 (SWO/TDO), R23.2
unnamed: J4.10 (~RESET), R20.2
unnamed: Q1.1 (G), R28.2, R29.1, TP19.1
unnamed: R14.2, SW1.2
unnamed: C3.2, R3.2, R4.1, U1.5 (FB)
unnamed: L1.1, U1.3 (SW)
unnamed: R15.1, U4.5 (ILIMIT)
unnamed: R11.2, R12.1, U5.1 (+)
unnamed: R27.2, U6.18 (GPIO15)
unnamed: R17.1, U6.46 (USB_DM)
unnamed: R16.1, U6.47 (USB_DP)
unnamed: C14.2, C15.2, C16.2, U6.23 (DVDD), U6.45 (VREG_VOUT), U6.50 (DVDD)
unnamed: C11.1, U6.20 (XIN), Y1.3
unnamed: R18.2, U6.21 (XOUT)

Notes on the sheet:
Red
GPIO3 (TARGET_VREF_PWR_EN) and GPIO16 define device type (GPIO3, GPIO16): (0, float) - native MioLink; (0, 0) - MioLink_Pico (adapter board for Pico and Pico W); (float, float) - Pico or Pico W.
Target buffers
Current limit is set to ~350mA
Yellow
3V3 Power
MCU with QSPI Flash
Green
GPIO14 and GPIO15 determine hardware revision: (0, 0 - revA) (0, 1 - revB)
Target power and Vref measure
Orange
Target connector
LEDs
USB

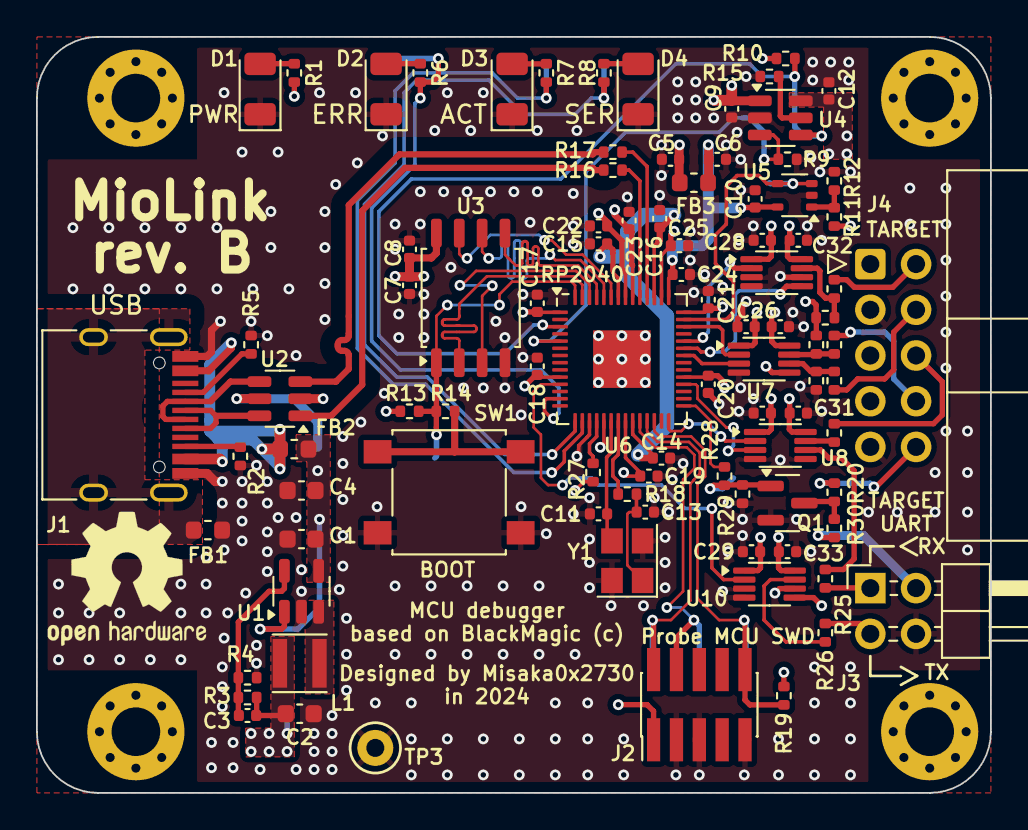
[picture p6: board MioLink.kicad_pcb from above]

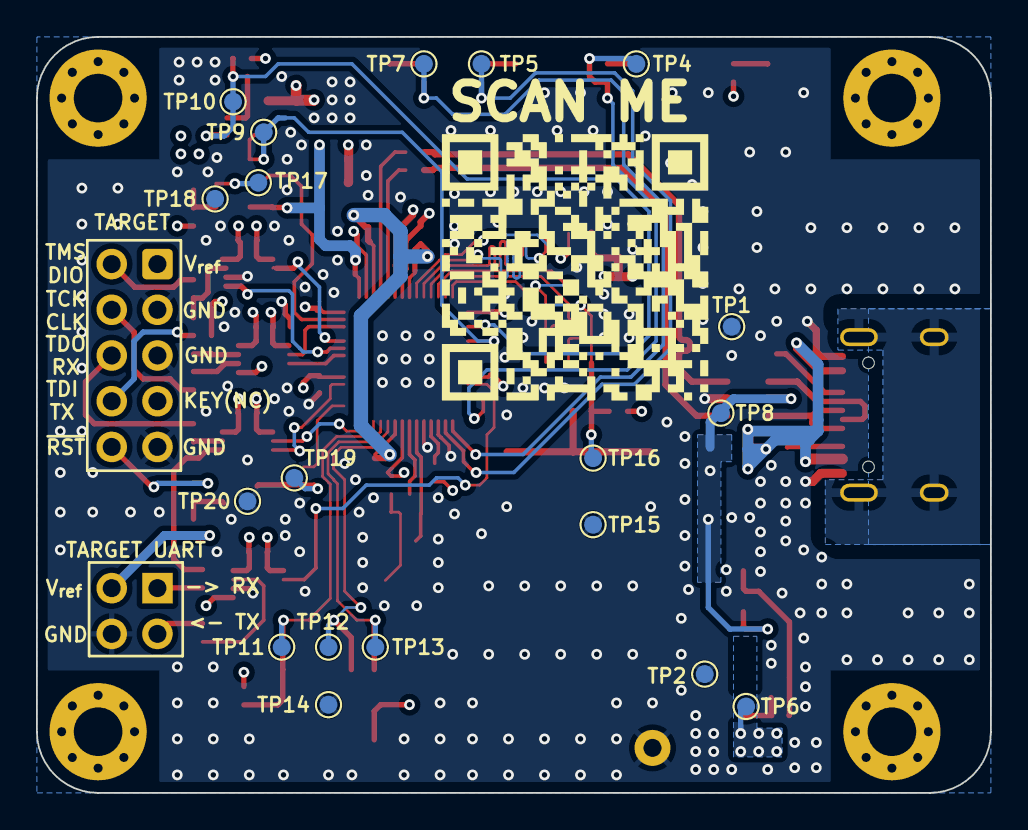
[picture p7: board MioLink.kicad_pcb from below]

Board: 4 copper layers, 53.0 x 42.0 mm, 117 parts (20 on the bottom side), 67 nets.

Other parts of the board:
G1: LOGO
REF1, REF2, REF3, REF4: MountingHole_2.7mm_M2.5_Pad_Via
REF5: OSHW-Logo2_9.8x8mm_SilkScreen

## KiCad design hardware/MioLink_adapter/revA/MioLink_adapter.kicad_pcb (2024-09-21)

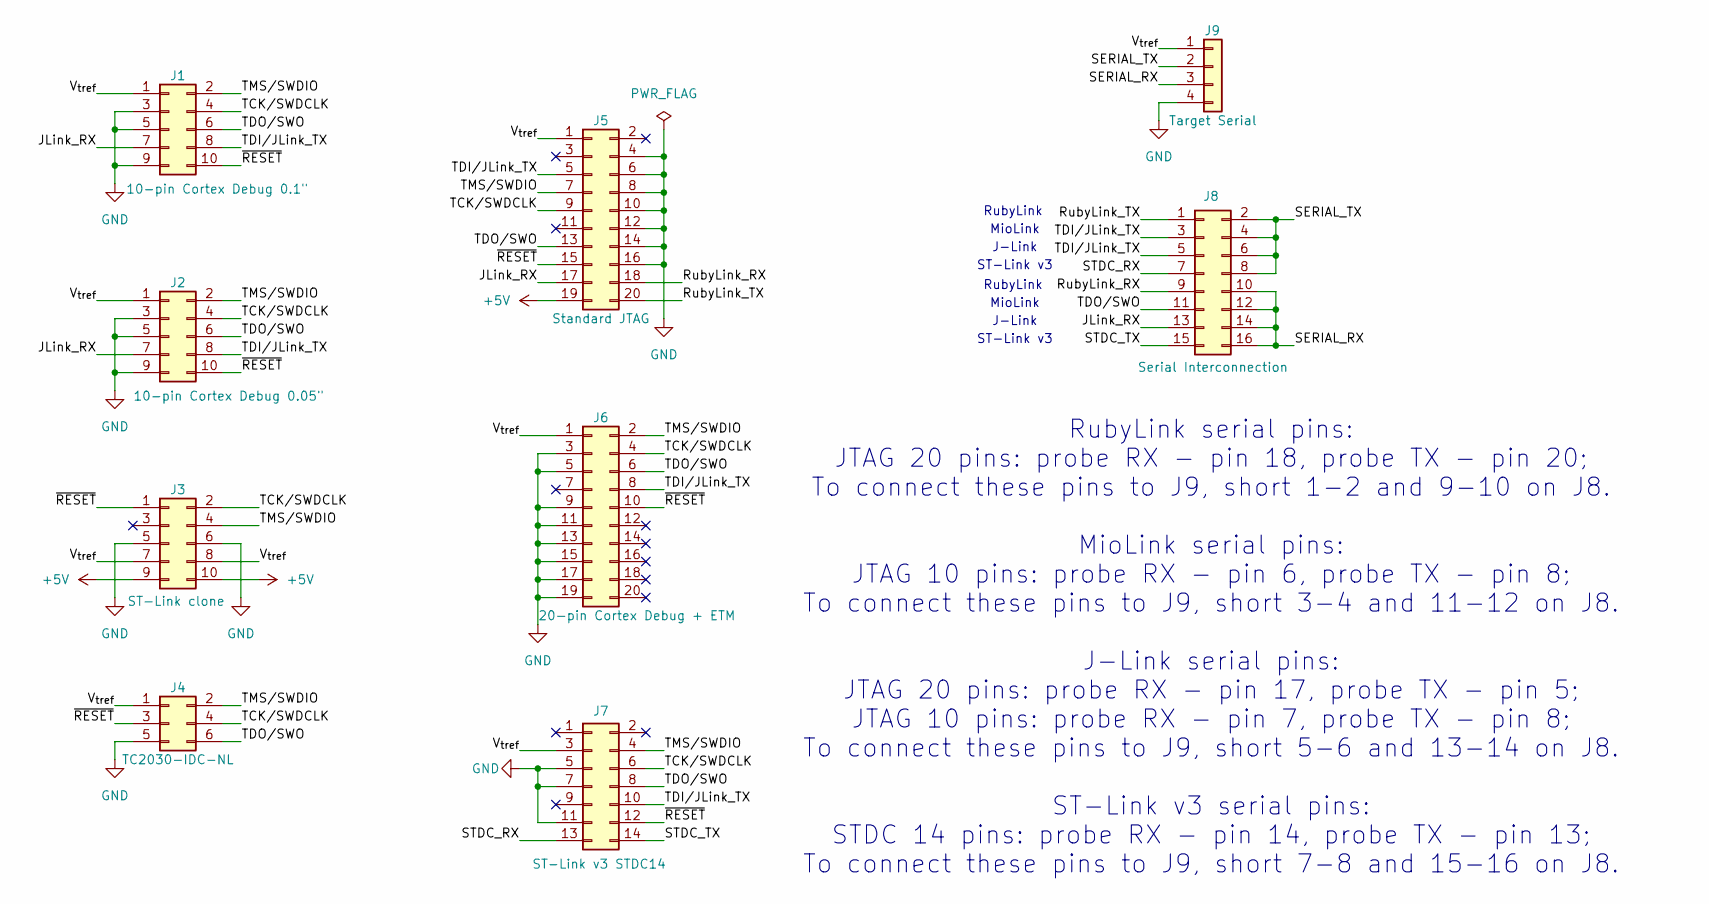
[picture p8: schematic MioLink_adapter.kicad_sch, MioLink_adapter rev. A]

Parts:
J1: 10-pin Cortex Debug 0.1"; IDC-Header_2x05_P2.54mm_Vertical
J2: 10-pin Cortex Debug 0.05"; PinHeader_2x05_P1.27mm_Vertical_SMD
J3: ST-Link clone; IDC-Header_2x05_P2.54mm_Vertical
J4: TC2030-IDC-NL; PinHeader_2x03_P2.54mm_Vertical
J5: Standard JTAG; IDC-Header_2x10_P2.54mm_Vertical
J6: 20-pin Cortex Debug + ETM; PinHeader_2x10_P1.27mm_Vertical_SMD
J7: ST-Link v3 STDC14; PinHeader_2x07_P1.27mm_Vertical_SMD
J8: Serial Interconnection; PinHeader_2x08_P2.54mm_Vertical
J9: Target Serial; PinHeader_1x04_P2.54mm_Horizontal

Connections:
+5V: J3.9, J3.10, J5.19
/JLink_RX: J1.7, J2.7, J5.17, J8.13
/RubyLink_RX: J5.18, J8.9
/RubyLink_TX: J5.20, J8.1
/SERIAL_RX: J8.10, J8.12, J8.14, J8.16, J9.3
/SERIAL_TX: J8.2, J8.4, J8.6, J8.8, J9.2
/STDC_RX: J7.13, J8.7
/STDC_TX: J7.14, J8.15
/TCK/SWDCLK: J1.4, J2.4, J3.2, J4.4, J5.9, J6.4, J7.6
/TDI/JLink_TX: J1.8, J2.8, J5.5, J6.8, J7.10, J8.3, J8.5
/TDO/SWO: J1.6, J2.6, J4.6, J5.13, J6.6, J7.8, J8.11
/TMS/SWDIO: J1.2, J2.2, J3.4, J4.2, J5.7, J6.2, J7.4
/V_{tref}: J1.1, J2.1, J3.7, J3.8, J4.1, J5.1, J6.1, J7.3, J9.1
/~RESET: J1.10, J2.10, J3.1, J4.3, J5.15, J6.10, J7.12
GND: J1.3, J1.5, J1.9, J2.3, J2.5, J2.9, J3.5, J3.6, J4.5, J5.4, J5.6, J5.8, J5.10, J5.12, J5.14, J5.16, J6.3, J6.5, J6.9, J6.11, J6.13, J6.15, J6.17, J6.19, J7.5, J7.7, J7.11, J9.4

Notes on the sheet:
MioLink
ST-Link v3
RubyLink
J-Link
RubyLink serial pins: JTAG 20 pins: probe RX - pin 18, probe TX - pin 20; To connect these pins to J9, short 1-2 and 9-10 on J8. MioLink serial pins: JTAG 10 pins: probe RX - pin 6, probe TX - pin 8; To connect these pins to J9, short 3-4 and 11-12 on J8. J-Link serial pins: JTAG 20 pins: probe RX 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

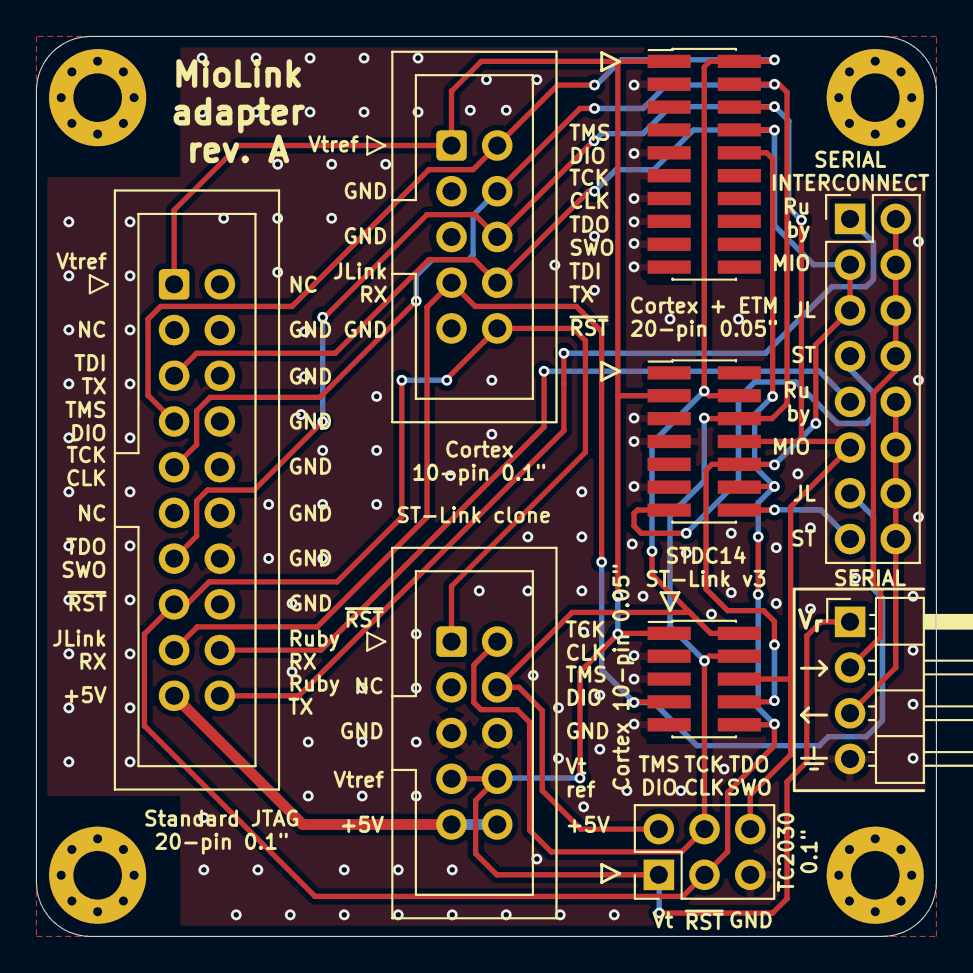
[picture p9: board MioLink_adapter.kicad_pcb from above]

Board: 2 copper layers, 50.0 x 50.0 mm, 13 parts (0 on the bottom side), 15 nets.

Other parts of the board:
REF1, REF2, REF3, REF4: MountingHole_2.7mm_M2.5_Pad_Via

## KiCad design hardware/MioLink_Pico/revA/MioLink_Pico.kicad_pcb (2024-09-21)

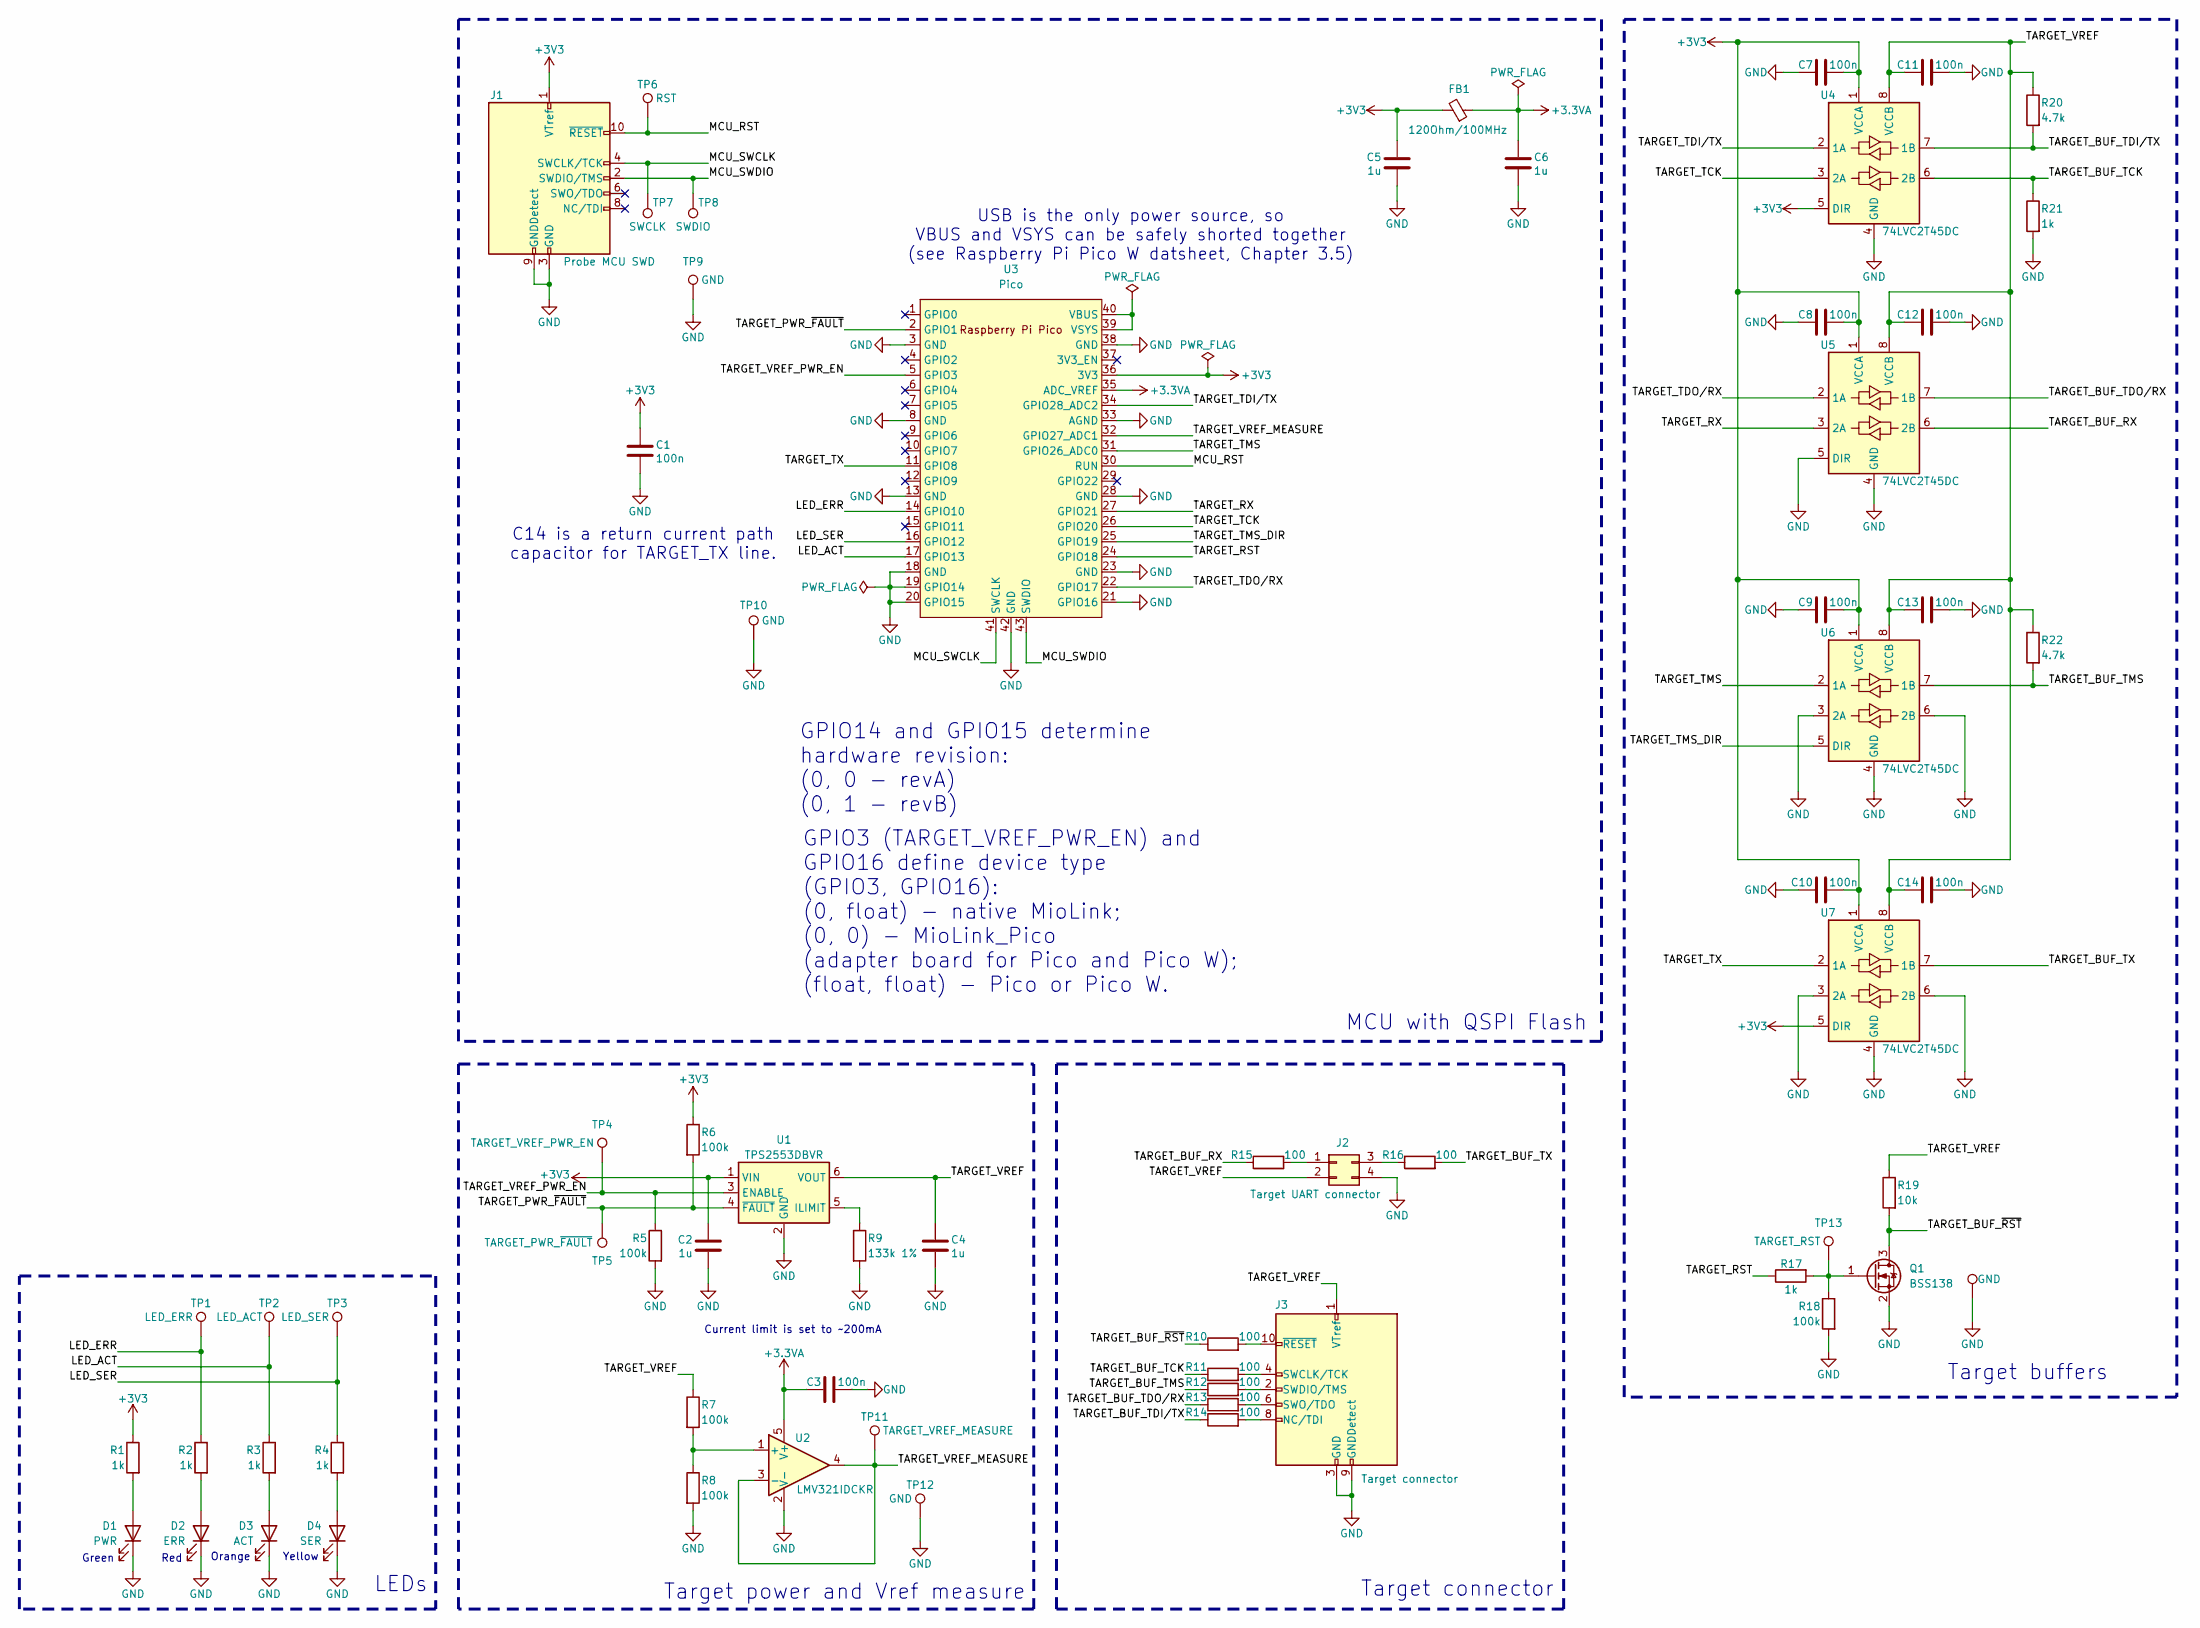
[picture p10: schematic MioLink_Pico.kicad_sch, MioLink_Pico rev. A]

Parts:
C1, C3, C7, C8, C9, C10, C11, C12, C13, C14: 100n; C_0402_1005Metric; Part Number CL05B104KO5NNNC; LCSC C1525
C2, C4, C5, C6: 1u; C_0402_1005Metric; Part Number CL05A105KA5NQNC; LCSC C52923
D1: PWR; LED_1206_3216Metric; Part Number XL-3216SYGC; LCSC C965826
D2: ERR; LED_1206_3216Metric; Part Number XL-3216SURC; LCSC C965822
D3: ACT; LED_1206_3216Metric; Part Number XL-3216UOC; LCSC C965823
D4: SER; LED_1206_3216Metric; Part Number XL-3216UYC; LCSC C965824
FB1: 120Ohm/100MHz; L_0603_1608Metric; Part Number BLM18PG121SN1D; LCSC C14709
J1: Probe MCU SWD; PinHeader_2x05_P1.27mm_Vertical_SMD; Part Number 20021121-00010T4LF; LCSC C598540
J2: Target UART connector; PinHeader_2x02_P2.54mm_Horizontal; Part Number PZ254-2-02-W-8.5; LCSC C2894982
J3: Target connector; IDC-Header_2x05_P2.54mm_Horizontal; Part Number 0502A001A1BC; LCSC C7434504
Q1: BSS138; SOT-23; Part Number BSS138LT1G; LCSC C82045
R1, R2, R3, R4, R17, R21: 1k; R_0402_1005Metric; Part Number 0402WGF1001TCE; LCSC C11702
R5, R6, R7, R8, R18: 100k; R_0402_1005Metric; Part Number 0402WGF1003TCE; LCSC C25741
R9: 133k 1%; R_0402_1005Metric; Part Number 0402WGF1333TCE; LCSC C25753
R10, R11, R12, R13, R14, R15, R16: 100; R_0402_1005Metric; Part Number 0402WGF1000TCE; LCSC C25076
R19: 10k; R_0402_1005Metric; Part Number 0402WGF1002TCE; LCSC C25744
R20, R22: 4.7k; R_0402_1005Metric; Part Number 0402WGF4701TCE; LCSC C25900
TP1: LED_ERR; TestPoint_Pad_D1.0mm
TP2: LED_ACT; TestPoint_Pad_D1.0mm
TP3: LED_SER; TestPoint_Pad_D1.0mm
TP4: TARGET_VREF_PWR_EN; TestPoint_Pad_D1.0mm
TP5: TARGET_PWR_~{FAULT}; TestPoint_Pad_D1.0mm
TP6: RST; TestPoint_Pad_D1.0mm
TP7: SWCLK; TestPoint_Pad_D1.0mm
TP8: SWDIO; TestPoint_Pad_D1.0mm
TP9, TP12, TP14: GND; TestPoint_Pad_D1.0mm
TP10: GND; TestPoint_Keystone_5000-5004_Miniature
TP11: TARGET_VREF_MEASURE; TestPoint_Pad_D1.0mm
TP13: TARGET_RST; TestPoint_Pad_D1.0mm
U1: TPS2553DBVR; SOT-23-6; Part Number TPS2553DBV; LCSC C55266
U2: LMV321IDCKR; SOT-353_SC-70-5; Part Number LMV321IDCKR; LCSC C3029047
U3: Pico; RPi_Pico_SMD_TH
U4, U5, U6, U7: 74LVC2T45DC; VSSOP-8_2.3x2mm_P0.5mm; Part Number SN74LVC2T45DCU; LCSC C22356905

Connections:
+3.3VA: C3.1, C6.1, FB1.1, U2.5 (V+), U3.35 (ADC_VREF)
+3V3: C1.2, C2.1, C5.1, C7.1, C8.1, C9.1, C10.1, FB1.2, J1.1 (VTref), R1.1, R6.1, U1.1 (VIN), U3.36 (3V3), U4.1 (VCCA), U4.5 (DIR), U5.1 (VCCA), U6.1 (VCCA), U7.1 (VCCA), U7.5 (DIR)
/LED_ACT: R3.1, TP2.1, U3.17 (GPIO13)
/LED_ERR: R2.1, TP1.1, U3.14 (GPIO10)
/LED_SER: R4.1, TP3.1, U3.16 (GPIO12)
/MCU_RST: J1.10 (~RESET), TP6.1, U3.30 (RUN)
/MCU_SWCLK: J1.4 (SWCLK/TCK), TP7.1, U3.41 (SWCLK)
/MCU_SWDIO: J1.2 (SWDIO/TMS), TP8.1, U3.43 (SWDIO)
/TARGET_BUF_RX: R15.1, U5.6 (2B)
/TARGET_BUF_TCK: R11.1, R21.1, U4.6 (2B)
/TARGET_BUF_TDI/TX: R14.1, R20.2, U4.7 (1B)
/TARGET_BUF_TDO/RX: R13.1, U5.7 (1B)
/TARGET_BUF_TMS: R12.1, R22.2, U6.7 (1B)
/TARGET_BUF_TX: R16.2, U7.7 (1B)
/TARGET_BUF_~RST: Q1.3 (D), R10.1, R19.2
/TARGET_PWR_~FAULT: R6.2, TP5.1, U1.4 (~FAULT), U3.2 (GPIO1)
/TARGET_RST: R17.1, U3.24 (GPIO18)
/TARGET_RX: U3.27 (GPIO21), U5.3 (2A)
/TARGET_TCK: U3.26 (GPIO20), U4.3 (2A)
/TARGET_TDI/TX: U3.34 (GPIO28_ADC2), U4.2 (1A)
/TARGET_TDO/RX: U3.22 (GPIO17), U5.2 (1A)
/TARGET_TMS: U3.31 (GPIO26_ADC0), U6.2 (1A)
/TARGET_TMS_DIR: U3.25 (GPIO19), U6.5 (DIR)
/TARGET_TX: U3.11 (GPIO8), U7.2 (1A)
/TARGET_VREF: C4.1, C11.2, C12.2, C13.2, C14.2, J2.2, J3.1 (VTref), R7.1, R19.1, R20.1, R22.1, U1.6 (VOUT), U4.8 (VCCB), U5.8 (VCCB), U6.8 (VCCB), U7.8 (VCCB)
/TARGET_VREF_MEASURE: TP11.1, U2.3 (-), U2.4, U3.32 (GPIO27_ADC1)
/TARGET_VREF_PWR_EN: R5.1, TP4.1, U1.3 (ENABLE), U3.5 (GPIO3)
GND: C1.1, C2.2, C3.2, C4.2, C5.2, C6.2, C7.2, C8.2, C9.2, C10.2, C11.1, C12.1, C13.1, C14.1, D1.1 (K), D2.1 (K), D3.1 (K), D4.1 (K), J1.3 (GND), J1.5 (GND), J1.9 (GNDDetect), J2.4, J3.3 (GND), J3.5 (GND), J3.9 (GNDDetect), Q1.2 (S), R5.2, R8.2, R9.2, R18.2, R21.2, TP9.1, TP10.1, TP12.1, TP14.1, U1.2 (GND), U2.2 (V-), U3.3 (GND), U3.8 (GND), U3.13 (GND), U3.18 (GND), U3.19 (GPIO14), U3.20 (GPIO15), U3.21 (GPIO16), U3.23 (GND), U3.28 (GND), U3.33 (AGND), U3.38 (GND), U3.42 (GND), U4.4 (GND), U5.4 (GND), U5.5 (DIR), U6.3 (2A), U6.4 (GND), U6.6 (2B), U7.3 (2A), U7.4 (GND), U7.6 (2B)
unnamed: D1.2 (A), R1.2
unnamed: D2.2 (A), R2.2
unnamed: D3.2 (A), R3.2
unnamed: D4.2 (A), R4.2
unnamed: J2.1, R15.2
unnamed: J2.3, R16.1
unnamed: J3.8 (NC/TDI), R14.2
unnamed: J3.4 (SWCLK/TCK), R11.2
unnamed: J3.2 (SWDIO/TMS), R12.2
unnamed: J3.6 (SWO/TDO), R13.2
unnamed: J3.10 (~RESET), R10.2
unnamed: Q1.1 (G), R17.2, R18.1, TP13.1
unnamed: R9.1, U1.5 (ILIMIT)
unnamed: R7.2, R8.1, U2.1 (+)
unnamed: U3.39 (VSYS), U3.40 (VBUS)

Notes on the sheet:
Red
Target buffers
Current limit is set to ~200mA
GPIO3 (TARGET_VREF_PWR_EN) and GPIO16 define device type (GPIO3, GPIO16): (0, float) - native MioLink; (0, 0) - MioLink_Pico (adapter board for Pico and Pico W); (float, float) - Pico or Pico W.
Yellow
MCU with QSPI Flash
Green
GPIO14 and GPIO15 determine hardware revision: (0, 0 - revA) (0, 1 - revB)
Target power and Vref measure
Orange
Target connector
LEDs
C14 is a return current path capacitor for TARGET_TX line.
USB is the only power source, so VBUS and VSYS can be safely shorted together (see Raspberry Pi Pico W datsheet, Chapter 3.5)

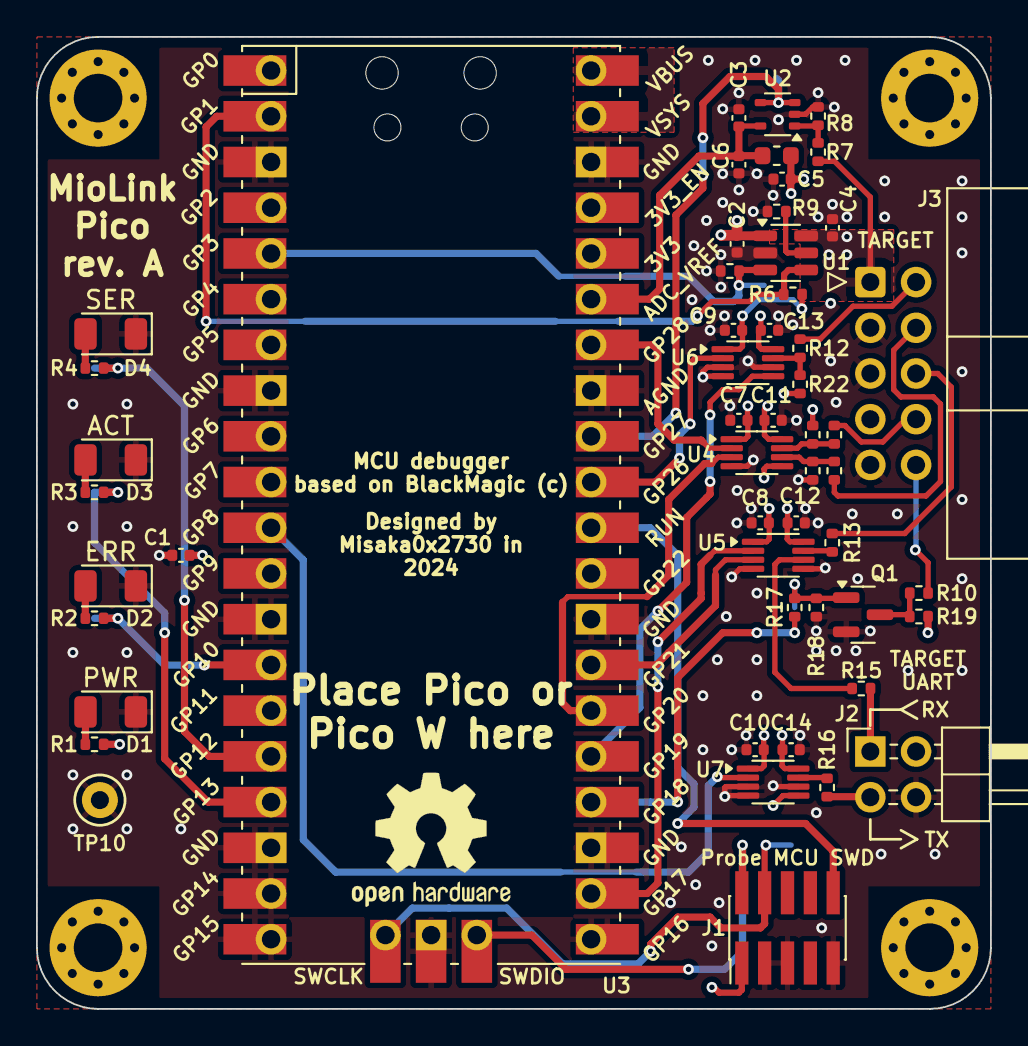
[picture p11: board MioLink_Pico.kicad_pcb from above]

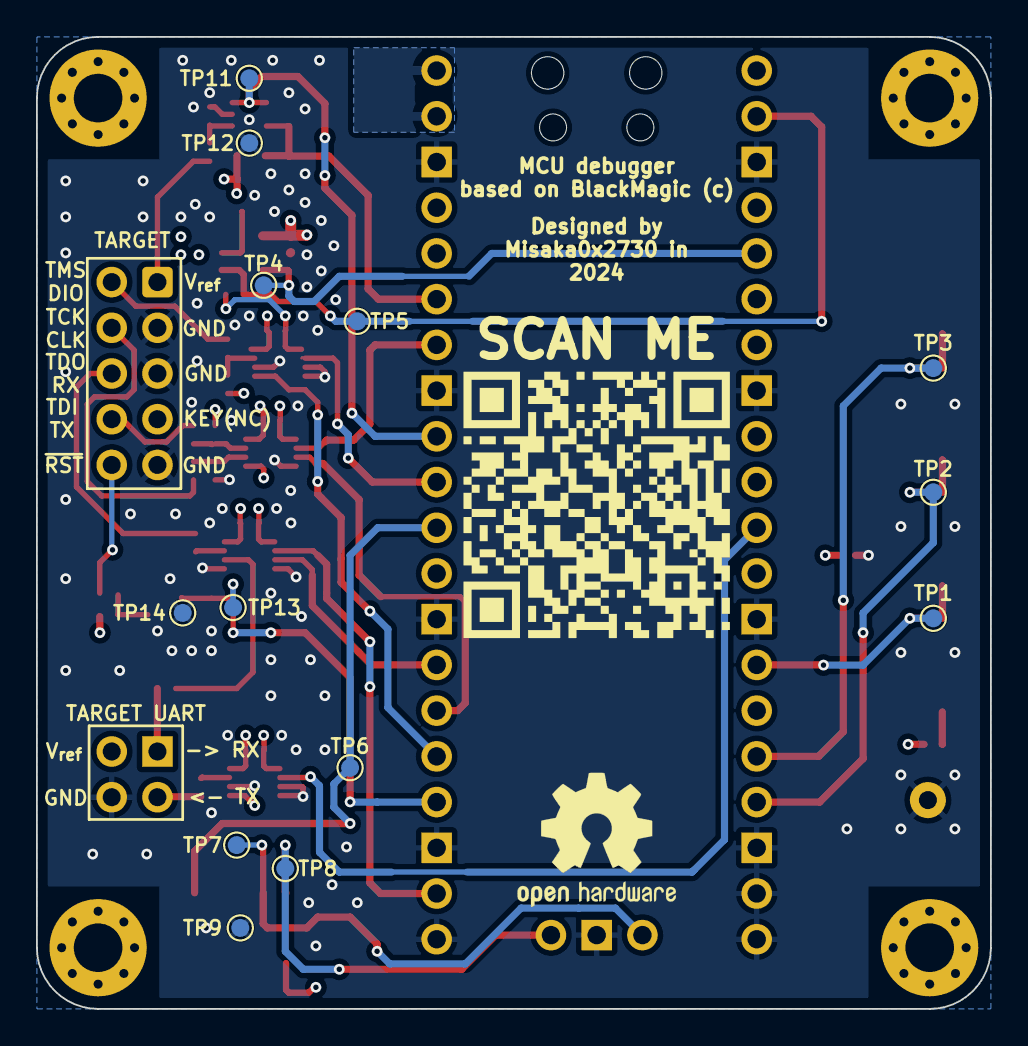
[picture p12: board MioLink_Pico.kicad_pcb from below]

Board: 4 copper layers, 53.0 x 54.0 mm, 73 parts (15 on the bottom side), 43 nets.

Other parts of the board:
G1: LOGO
REF1, REF2, REF3, REF4: MountingHole_2.7mm_M2.5_Pad_Via
REF5, REF6: OSHW-Logo2_9.8x8mm_SilkScreen

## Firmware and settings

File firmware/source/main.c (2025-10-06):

/*
 * This file is part of the Black Magic Debug project.
 *
 * Copyright (C) 2011  Black Sphere Technologies Ltd.
 * Written by Gareth McMullin <gareth@blacksphere.co.nz>
 * Modified by Dmitry Rezvanov <dmitry.rezvanov@yandex.ru>
 *
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
 * You should have received a copy of the GNU General Public License
 * along with this program.  If not, see <http://www.gnu.org/licenses/>.
 */

/* Provides main entry point. Initialise subsystems and enter GDB protocol loop. */

#include "general.h"
#include "platform.h"

#include "pico/multicore.h"

#include "FreeRTOS.h"
#include "task.h"

#include "usb_serial.h"
#include "usb.h"

#ifdef ENABLE_RTT
#include "rtt.h"
#endif

#ifdef PLATFORM_HAS_TRACESWO
#include "swo.h"
#endif

#if ENABLE_DEBUG
#include "SEGGER_RTT.h"
#endif

#include "gdb_if.h"
#include "gdb_main.h"
#include "target.h"
#include "exception.h"
#include "gdb_packet.h"
#include "morse.h"

#define GDB_TASK_CORE_AFFINITY (0x02) /* Core 1 only */
#define GDB_TASK_STACK_SIZE    (2048)

TaskHandle_t gdb_task;

static void bmp_poll_loop(void)
{
	SET_IDLE_STATE(false);
	while (gdb_target_running && cur_target) {
		gdb_poll_target();

		// Check again, as `gdb_poll_target()` may
		// alter these variables.
		if (!gdb_target_running || !cur_target)
			break;
		char c = gdb_if_getchar_to(0);
		if (c == '\x03' || c == '\x04')
			target_halt_request(cur_target);
#ifdef ENABLE_RTT
		if (rtt_enabled)
			poll_rtt(cur_target);
#endif
	}

	SET_IDLE_STATE(true);
	const gdb_packet_s *const packet = gdb_packet_receive();
	// If port closed and target detached, stay idle
	if (packet->data[0] != '\x04' || cur_target)
		SET_IDLE_STATE(false);
	gdb_main(packet);
}

_Noreturn static void gdb_thread(void *params)
{
	(void)params;

	while (1) {
		TRY (EXCEPTION_ALL) {
			bmp_poll_loop();
		}
		CATCH () {
		default:
			gdb_put_packet_error(0xffU);
			target_list_free();
			gdb_outf("Uncaught exception: %s\n", exception_frame.msg);
			morse("TARGET LOST.", true);
		}
	}
}

void main(void)
{
#if ENABLE_DEBUG
	SEGGER_RTT_Init();
#endif

#if ENABLE_SYSVIEW_TRACE
	traceSTART();
#endif

	platform_update_sys_freq();

	platform_init();
	blackmagic_usb_init();
	usb_serial_init();
	traceswo_task_init();

	multicore_reset_core1();

#if configUSE_CORE_AFFINITY
	const BaseType_t result = xTaskCreateAffinitySet(
		gdb_thread, "target_gdb", GDB_TASK_STACK_SIZE, NULL, PLATFORM_PRIORITY_LOW, GDB_TASK_CORE_AFFINITY, &gdb_task);
#else
	const BaseType_t result =
		xTaskCreate(gdb_thread, "target_gdb", GDB_TASK_STACK_SIZE, NULL, PLATFORM_PRIORITY_LOW, &gdb_task);
#endif

	assert(result == pdPASS);

	vTaskStartScheduler();

	assert(false);
}

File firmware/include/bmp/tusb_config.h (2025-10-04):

/*
 * The MIT License (MIT)
 *
 * Copyright (c) 2019 Ha Thach (tinyusb.org)
 * Modified by Dmitry Rezvanov <dmitry.rezvanov@yandex.ru>
 *
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
 */

#ifndef MIOLINK_TUSB_CONFIG_H
#define MIOLINK_TUSB_CONFIG_H

#ifdef __cplusplus
extern "C" {
#endif

//--------------------------------------------------------------------
// COMMON CONFIGURATION
//--------------------------------------------------------------------

// defined by board.mk
#ifndef CFG_TUSB_MCU
#error CFG_TUSB_MCU must be defined
#endif

// RHPort number used for device can be defined by board.mk, default to port 0
#ifndef BOARD_DEVICE_RHPORT_NUM
#define BOARD_DEVICE_RHPORT_NUM 0
#endif

// RHPort max operational speed can be defined by board.mk
// Default to Highspeed for MCU with internal HighSpeed PHY (can be port specific), otherwise FullSpeed
#ifndef BOARD_DEVICE_RHPORT_SPEED
#if (CFG_TUSB_MCU == OPT_MCU_LPC18XX || CFG_TUSB_MCU == OPT_MCU_LPC43XX || CFG_TUSB_MCU == OPT_MCU_MIMXRT10XX || \
	CFG_TUSB_MCU == OPT_MCU_NUC505 || CFG_TUSB_MCU == OPT_MCU_CXD56 || CFG_TUSB_MCU == OPT_MCU_SAMX7X)
#define BOARD_DEVICE_RHPORT_SPEED OPT_MODE_HIGH_SPEED
#else
#define BOARD_DEVICE_RHPORT_SPEED OPT_MODE_FULL_SPEED
#endif
#endif

// Device mode with rhport and speed defined by board.mk
#if BOARD_DEVICE_RHPORT_NUM == 0
#define CFG_TUSB_RHPORT0_MODE (OPT_MODE_DEVICE | BOARD_DEVICE_RHPORT_SPEED)
#elif BOARD_DEVICE_RHPORT_NUM == 1
#define CFG_TUSB_RHPORT1_MODE (OPT_MODE_DEVICE | BOARD_DEVICE_RHPORT_SPEED)
#else
#error "Incorrect RHPort configuration"
#endif

#ifndef CFG_TUSB_MEM_SECTION
#define CFG_TUSB_MEM_SECTION
#endif

#ifndef CFG_TUSB_MEM_ALIGN
#define CFG_TUSB_MEM_ALIGN __attribute__((aligned(4)))
#endif

//--------------------------------------------------------------------
// DEVICE CONFIGURATION
//--------------------------------------------------------------------

#ifndef CFG_TUD_ENDPOINT0_SIZE
#define CFG_TUD_ENDPOINT0_SIZE 64
#endif

//------------- CLASS -------------//
#define CFG_TUD_CDC         2
#define CFG_TUD_MSC         0
#define CFG_TUD_HID         0
#define CFG_TUD_MIDI        0
#define CFG_TUD_VENDOR      1
#define CFG_TUD_DFU_RUNTIME 1

// CDC FIFO size of TX and RX
#if !defined(CFG_TUD_CDC_RX_BUFSIZE)
#define CFG_TUD_CDC_RX_BUFSIZE 2048
#endif

#if !defined(CFG_TUD_CDC_TX_BUFSIZE)
#define CFG_TUD_CDC_TX_BUFSIZE 4096
#endif

#if !defined(CFG_TUD_CDC_EP_BUFSIZE)
#define CFG_TUD_CDC_EP_BUFSIZE 2048
#endif

#if !defined(CFG_TUD_VENDOR_EPSIZE)
#define CFG_TUD_VENDOR_EPSIZE 64
#endif

#if !defined(CFG_TUD_VENDOR_RX_BUFSIZE)
#define CFG_TUD_VENDOR_RX_BUFSIZE 64
#endif

#if !defined(CFG_TUD_VENDOR_TX_BUFSIZE)
#define CFG_TUD_VENDOR_TX_BUFSIZE 2048
#endif

#ifdef __cplusplus
}
#endif

#endif /* MIOLINK_TUSB_CONFIG_H */

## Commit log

2024-06-19 revA hardware (SCH+PCB) finished development
    [MioLink.kicad_pcb, MioLink.kicad_sch]
2024-06-19 Updated part numbers
    [MioLink.kicad_pcb, MioLink.kicad_sch]
2024-07-16 Finished revA, added JLCPCB production files
    [BOM-MioLink.csv, MioLink.kicad_pcb, MioLink.kicad_sch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]
2024-08-04 Added PIOSM SWD implementation, added crc32 implementation on RP2040 DMA
2024-08-04 Use RP2040 crc32 implementation in CMakeLists, use registers instead of SDK calls in swdptap_seq_out_parity, fixed target interface frequency calcualtion (removed flaot)
    [platform.h, swdptap.c]
2024-08-09 JTAG PIO program rework. Added common functions to work with PIO in tap_pio_common.h
    [jtagtap.c, platform.h, swdptap.c]
2024-08-09 Minor PIO jtag/swd fixes
    [jtagtap.c, swdptap.c]
2024-08-14 Removed RubyLink platform. Rework USB-UART module.
    [main.c, platform.c, platform.h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]
2024-08-15 Added automatic git version generating for BMP and FreeRTOS. Added RTT driver (rtt_if).
2024-08-17 Added TRACESWO support (UART only), added TRACE and DFU interfaces in USB descriptors
2024-08-17 Added support for the UART on TDI/TDO pins feature (command "monitor uart_on_tdi_tdo")
2024-08-19 Use GCC printf instead of Pico SDK implementation
2024-08-19 Removed hack for using tinyusb FreeRTOS support instead of Pico SDK. Reworked send_to_usb function
    [platform.c, traceswoasync.c, usb.c]
2024-08-19 Added missed header tusb_config.h
    [tusb_config.h]
2024-08-23 Fixed comment for Microsoft OS 2.0 descriptor
    [usb.c]
2024-08-29 Major usb_serial, traceswo refactoring
2024-09-21 Global project rework, added hardware project files: MioLink revB, MioLink adapter revA, MioLink Pico revA (main board for Pico and Pico W)
    [BOM-MioLink.csv, BOM-MioLink_Pico.csv, BOM-MioLink_adapter.csv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]
2024-09-23 Fixed problems with release build
    [main.c, traceswoasync.c, usb.c]
2024-09-23 Added schematics in .pdf
2024-10-03 Fixed a lot of minor issues, added Pico and Pico W support
    [MioLink.kicad_sch, MioLink_Pico.kicad_sch]
2024-10-04 Updated copyright, delay in pio programs, schematic pdf's
2024-10-08 Global code cleanup, fixed a lot of minor moments. Added description to SWD/JTAG PIO programs
    [jtagtap.c, main.c, platform.c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]
2024-10-11 Rework SWD PIO programs, split programs and use all state machines
    [jtagtap.c, swdptap.c]
2024-11-02 Reworked SWD code (DMA is used to send data to the PIO TX FIFO), minor changes, moved GDB thread to Core 1
    [main.c, swdptap.c, traceswoasync.c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]
2024-11-02 Rework JTAG code, use DMA to send data to PIO TX FIFO
    [jtagtap.c, swdptap.c]
2024-11-24 Fixed the HW version pins numbers
    [platform.h]
2025-02-27 Update .gitignore to ignore picotool and test board files
2025-10-04 Updated third-party libraries, resolved conflicts
    [platform.h]
2025-10-04 Add TRACESWO Manchester mode support
2025-10-04 Update TRACESWO Manchester mode to use 12 cycles per bit
2025-10-04 Minor refactoring USB serial and traceswo
2025-10-06 Fixed bug with incorrect SWD frequency
    [main.c]
2025-10-06 Fixed PIO gpio configuration
    [swdptap.c, traceswoasync.c]

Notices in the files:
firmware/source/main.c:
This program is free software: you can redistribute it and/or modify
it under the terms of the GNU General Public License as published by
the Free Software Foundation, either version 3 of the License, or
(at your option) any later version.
